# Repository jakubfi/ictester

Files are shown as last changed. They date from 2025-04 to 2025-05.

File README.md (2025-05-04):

# Logic IC Tester
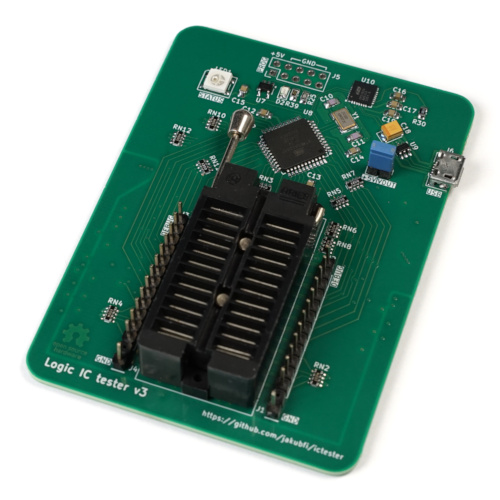
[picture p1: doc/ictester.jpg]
IC Tester

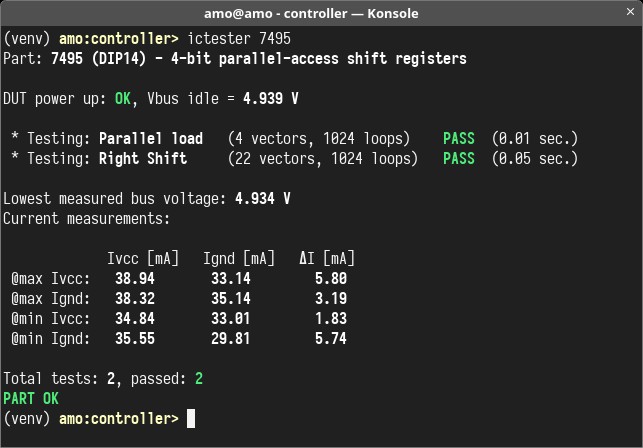
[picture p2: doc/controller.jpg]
Software


Main goal of this project was to make a logic IC tester that allows adding new tests and support for new ICs easily.

## Features

* fully programmable (client-side, in python)
* designed for 5 V TTL logic, but other 5 V logic families can be tested too
* current limiting to 200mA
* current and voltage measurement on VCC and GND pins
* 1.7 μs (<=16-pin ICs) and 2.15 μs (>16-pin ICs) per single logic test cycle
* built-in tests for 4164 and 41256 memories (MARCH C- test in read+write, read/write and page access modes)
* built-in tests for 74121, 74122 and 74123 univibrators
* small and USB powered

## Components

Project is split into three parts:

* [controller](controller) - software for controlling the tester. Look there for command line usage.
* [firmware](fw) - IC tester firmware
* [hardware](hw) - KiCad project files (see also [this pdf](doc/ictester.pdf) for schematic)

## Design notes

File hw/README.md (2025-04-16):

KiCad project files for Logic IC Tester.

See also [pdf schematic](../doc/ictester.pdf)

# Connectors and jumpers

* J1, J2, J3, J4 - debug connectors. Duplicate ZIF socket connections (plus additional GND connections) and allow
  connecting external measurement equipment. Can also be used for testing ICs and circuits outside the ZIF socket.
* J5 - MCU programmer interface.
* J6 - USB port
* J7 - jumper shorting +5V to DUT power supply lines. Normally closed. Can be used for measuring IC current
  or for supplying the IC with external power.

# CP2102N setup

To complete the hardware setup, CP2102N USB UART transceiver needs to be programmed with the following values:

* iManufacturer = mera400.pl
* iProduct = ictester
* MaxPower = 200mA

One possible way of programming it is to use [this](https://github.com/VCTLabs/cp210x-program/tree/master/ext/badge) tool:

`cp2102 -p "ictester" -m "mera400.pl" -x 200`

You can also use one of the tools provided by the manufacturer - Silicon Labs.

This step is not required, although without it no device autodetection will be possible.

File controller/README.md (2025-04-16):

# Logic IC Tester Control Software

This software communincates with the logic IC tester using [binary protocol](../doc/protocol.md) over a serial connection.
It first sets up all the DUT connections according to IC pin description and then runs tests for the selected IC.

# Installation

For both Linux and Windows installation requirements are the same:

* `python` >=3.6
* `git`

Note for Windows users: both git and python need to be available in your PATH for the installation to work.

Optionally create a new virtual environment:
```
virtualenv ictester
. ictester/bin/activate
```

Install the package:
```
pip install -e "git+https://github.com/jakubfi/ictester/#egg=ictester&subdirectory=controller"
```
Alternatively, clone the repo manually and install:
```
git clone https://github.com/jakubfi/ictester
cd ictester/controller
pip install .
```

# Usage

To list supported ICs use: `ictester --list`. `--list-all` will also list all tests for each part.
To run tests for a selected part use: `ictester <part>`.
To display help, use `ictester --help`

Note for Windows users: you'll need Silicon Labs CP210x USB to UART Bridge Driver installed
for the communication with IC tester to work. Also, device autodetection may fail.
In such case, use `--device COMx` option.

Other options when running a test:

* `-d DEVICE` or `--device DEVICE` - Serial port where the IC tester is connected. Required only when autodetection fails for some reason.
* `-l LOOPS` or `--loops LOOPS` - Test loop count (1..65535)
* `-t TEST` or `--test TEST` - Selects specific test to run
* `-D DELAY` or `--delay DELAY` - additional DUT output read delay in μs (for logic tests only, 13107 μs max, rounded to nearest 0.2 μs)
* `-v` or `--verbose` - Verbose output. Repeat for even more verbosity.
* `--safety-off` - Test the DUT even if overcurrent condition is detected.

Apart from the program output, tester hardware signals its state with a status LED:

* white - tester powered up and ready
* amber - DUT connected, test session running (do not remove the DUT from the socket)
* green - last test session finished with success (part is OK)
* red - last test session finished with failure (part is defective)
* purple - error encountered during session run

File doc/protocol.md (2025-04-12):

__WARNING: protocol is not yet finalized nor fully implemented__

# Overview

Dialog between the software and the tester are conducted using messages. There are two types of messages:

 * commands,
 * responses.

Dialog is always initiated with a command sent by the software controlling the tester. Tester always responds with a response.

All BYTES are unsigned. All WORDS are unsigned 16-bit values, little-endian.

## Available commands

| Command | Value | Description |
|---|---|---|
| `CMD_HELLO` | 1 | Check comms and get tester information |
| `CMD_DUT_SETUP` | 2 | Configure tester for the DUT |
| `CMD_DUT_POWERUP` | 3 | Power up the DUT |
| `CMD_TEST_SETUP` | 4 | Setup the test |
| `CMD_VECTORS_LOAD` | 5 | Load test vectors (optional, if used by the test) |
| `CMD_TEST_RUN` | 6 | Run the test |
| `CMD_DUT_DISCONNECT` | 7 | Power down the DUT, disconnect from the tester |

## Available responses

| Response | Value | Meaning |
|---|---|---|
| `RESP_HELLO` | 128 | Tester information |
| `RESP_OK` | 129 | Command executed |
| `RESP_PASS` | 130 | Test finished successfully |
| `RESP_FAIL` | 131 | Test finished with failure |
| `RESP_ERR` | 132 | Error |
| `RESP_TIMING_ERROR`  | 133 | Test finished with read timing error |

# Command description

## Hello

To verify that controlling software can work with the hardware, initial "Hello" handshake has to be performed.

### Command format

* 1 BYTE: command `CMD_HELLO`

### Valid responses

Tester always responds with `RESP_HELLO`, described in later section.

## DUT Setup

Before any other command, tester needs to be set up for the specific DUT.
This command informs the tester how to address DUT pins and sets ZIF socket pin functions for the DUT.
Protocol allows sending 1 or 2 pin configurations when setting up the DUT. One configuration is used
in most cases. Two configurations are required for DUTs with bidirectional pins, where pin roles
change from test to test.

### Command format

* 1 BYTE: command: `CMD_DUT_SETUP`
* 1 BYTE: `t` = package type (1=DIP)
* 1 BYTE: `p` = number of all DUT pins ([14, 16, 20, 24])
* 1 BYTE: `c` = number of pin configurations (min 1, max 4)
* `c` PIN CONFIGURATIONS (internally numbered starting from `0`):
  * `p` BYTES: `p` ZIF pin functions for each DUT pin. 1 byte each, starting from pin 1. See table below.

| ZIF Function | Value | MCU Pin Function | SW Function | Default DUT use |
|---|---|---|---|---|
| `ZIF_OUT` | 1 | output | - | TTL input |
| `ZIF_IN_HIZ` | 2 | input HiZ | - | TTL output, not connected  |
| `ZIF_IN_PU_STRONG`  | 3 | input HiZ | pull-up 4.7 kΩ | open-collector output |
| `ZIF_IN_PU_WEAK` | 4 | input with weak pullup | - | TTL output, 3-state output |
| `ZIF_OUT_SINK` | 5 | output driven low (sink)  | - | open-emitter |
| `ZIF_C` | 6 | input HiZ | capacitor 470 pF | univibrator C connection |
| `ZIF_OUT_SOURCE` | 7 | output driven high (sink) | - | - |
| `ZIF_VCC` | 128 | input HiZ | VDUT (+5 V) | VCC (+5 V) |
| `ZIF_GND` | 129 | input HiZ | GND | GND |

### Valid responses

* `RESP_OK` - DUT configuration accepted
* `RESP_ERR` - DUT configuration not accepted

## DUT Power Up

This command causes the tester to apply power to the DUT. Requires the DUT to be set up first.

DUT connection is done in 3 steps:

* connect GND and VCC pins,
* apply power to the VCC pin
* measure GND and VCC current and bus voltage

If measured current exceeds 190mA, overcurrent is reported and DUT is disconnected.

### Command format

* 1 BYTE: command: `CMD_DUT_POWERUP`
* 1 BYTE: safety\_off: 1=disable overcurrent check, 0=check for overcurrent

### Valid responses

* `RESP_OK` - DUT connected
* `RESP_ERR` - DUT cannot be connected

## DUT Disconnect

This command causes the tester to power down the DUT and deconfigure it's pin connections.
Note that DUT is also immediately disconnected by the tester if a test fails.

DUT disconnection is done in 3 steps:

* disconnect power to the DUT
* disconnect VCC, GND, pull-ups and C pins,
* drain charges from DUT pins and bypass caps
* deconfigure MCU pins (set all pins as HiZ)

### Command format

* 1 BYTE: command: `CMD_DUT_DISCONNECT`

### Valid responses

* `RESP_OK` - DUT disconnected

## Test Setup

Sets up the test. Requires the DUT to be set up first.

### Command format

* 1 BYTE: command: `CMD_TEST_SETUP`
* 1 BYTE: DUT pin configuration number used by the test
  (configuration `0` is available for every DUT, more may be available in some cases. See `CMD_DUT_SETUP`)
* 1 BYTE: test type. Algorithm used to test the DUT. See table below for test types available.
* TEST PARAMETERS: depend on the test type, see below.

| Test type | Value | Description |
|---|---|---|
| `TEST_LOGIC` | 1 | Logic ICs. Designed for 74 family, but suitable for other families too  |
| `TEST_DRAM` | 2 | 4164 and 41256 DRAM memories |
| `TEST_UNIVIB` | 3 | 74121, 74122 and 74123 monostable monovibrators |

### Valid responses

* `RESP_OK` - test setup successfull
* `RESP_ERR` - test setup failed

### Test types

Available test types and their specific requirements are described below.

#### Logic IC test

`TEST_LOGIC` (1) is designed to test 74 logic (both combinatorial and sequential), but suitable for many other IC families.
It's a basic, generic test that uses test vectors (uploaded with a separate command) to verify IC functionality by
setting its inputs to given values and checking if IC outputs match test vector outputs.

Test parameters:

* 1 WORD: additional delay (in 200 ns units) before checking DUT outputs. 0 for no delay.
* `n` BYTES: I/O pin usage in test vectors (n=2 for 14-pin and 16-pin devices, n=3 for >16-pin devices):
  * each bit: 1=I/O pin used by the test, 0=pin not used by the test
  * 1st byte contains lowest pin numbers, bit 0 in each byte describes pin with the lowest number

#### 4164 and 41256 DRAM memory test

`TEST_DRAM` (2) is designed to test 4164 and 41256 DRAM memory chips. There are three tests available, all using MARCH C- algorithm:

* read-modify-write - test is done using read-modify-write memory access,
* read+write - test is done using separate "read" and "write" operations,
* page mode - test is done using page reads and writes, treating the whole page as a single word.

Test parameters:

* 1 BYTE: tested device:
  * 1 = 4164 (64kbit),
  * 2 = 41256 (256kbit).
* 1 BYTE: test type:
  * 1 = read-modify-write,
  * 2 = read+write,
  * 3 = page mode.

#### 7412x univibrator test

`TEST_UNIVIB` (3) is designed to test 74121, 74122 and 74123 univibrators. Test does not use vectors and uses the following parameters:

* 1 BYTE: tested device:
  * 0 = 74121,
  * 1 = 74122,
  * 2 = 74123 univibrator 1,
  * 3 = 74123 univibrator 2
* 1 BYTE: test type:
  * 0 = conditions which should not trigger the device
  * 1 = conditions that should trigger the device
  * 2 = retrigger (not available for 74121)
  * 3 = clear (not available for 74121)
  * 4 = cross-trigger check (only for 74123)
  * 5 = trigger with rising clear edge (not available for 74121)

## Vectors upload

Upload test vectors. Requires the test to be set up first. Test needs to use vectors.

### Command format

* 1 BYTE: command: `CMD_VECTORS_LOAD`
* 1 WORD: `v` = number of test vectors, >0.
* `v` VECTORS

Each vector consists of 2 (for <=16-pin devices) or 3 (for >16-pin devices) BYTES.
Each byte contains bit values for 8 consecutive DUT pins.
For each input, bit value is set on DUT input. For each output, bit value is compared to DUT output. Bits map to pins as follow:

```
        .----.----.----.----.----.----.----.----.
BYTE 1: |  8 |  7 |  6 |  5 |  4 |  3 |  2 |  1 |
        +----.----.----.----.----.----.----.----+
BYTE 2: | 16 | 15 | 14 | 13 | 12 | 11 | 10 |  9 |
        +----.----.----.----.----.----.----.----+
BYTE 3: | 24 | 23 | 22 | 21 | 20 | 19 | 18 | 17 | (only for >16-pin devices)
        `----`----`----`----`----`----`----`----`
```

* Pins absent in the tested device are ignored (eg. for 14-pin devices two most significant bits of BYTE 2 are ignored).
* Non-I/O pins and pins not declared as inputs or outpus in the test are ignored, with one **exception** described below.

**Bit for VCC pin has a special meaning.**
Since it's never set nor read, tester uses it to decide whether DUT outputs should be checked at all.
If VCC pin is set to "1" for a given vector, test result for this vector is not checked.
Such vectors are used for DUT state setup and in sequential logic tests, where output has to be checked
only after the clock/strobe input changes.

### Valid responses

* `RESP_OK` - vectors uploaded successfully
* `RESP_ERR` - vector upload failed

## Run Test

Run the uploaded test. Requires test to be set and vectors to be uploaded (if required by the test).
If the test fails, DUT is immediately disconnected.

### Command format

* 1 BYTE: command: `CMD_TEST_RUN`
* 1 WORD: number of loops, 0 for infinite testing.

### Valid responses

* `RESP_ERR` - not possible to execute the test
* `RESP_PASS` - test executed, passed
* `RESP_FAIL` - test executed, failed

# Responses

## Hello

* 1 BYTE: `RESP_HELLO`
* 1 BYTE: protocol version
* 1 BYTE: firmware version
* 6 BYTES: reserved, unused but always sent and received

If protocol version reported by the hardware differs from protocol version supported
by the software, software refuses operation.
If firmware version is lower than supported by the software, operation can continue,
but not all tests available in the software can be run..
If firmware version is higher than supported by the software, operation can continue,
but not all features available in the hardware may be available to the software.

## Command OK

This response is sent when command has been successfully executed.

* 1 BYTE: response: `RESP_OK`

## Command error

This response is sent when a command cannot be executed or the execution failed.

* 1 BYTE: response: `RESP_ERR`
* 1 BYTE: error code from the table below

| Command | Value | Description |
|---|---|---|
| `ERR_UNKNOWN` | 0 | Error code was not set (likely a software bug) |
| `ERR_CMD_UNKNOWN` | 1 | Unknown command |
| `ERR_CMD_TOOBIG` | 2 | Command didn't fit in the receive buffer |
| `ERR_CRC` | 3 | CRC transmission error detected |
| | 4 | (unused) |
| `ERR_PACKAGE` | 5 | Unsupported package type |
| `ERR_PIN_CNT` | 6 | Unsupported pin count |
| `ERR_PIN_FUNC` | 7 | Unknown pin function |
| `ERR_PIN_COMB` | 8 | Bad pin function combination (eg. VCC+GND) |
| | 9 | (unused) |
| `ERR_TEST_TYPE` | 10 | Unsupported test type |
| | 11 | (unused) |
| `ERR_VECT_NUM` | 12 | Wrong number of test vectors (<1 or too many) |
| `ERR_PINCFG_CNT` | 13 | Wrong pin configuration count |
| `ERR_PINCFG_NUM` | 14 | Wrong pin configuration number (config not set) |
| | 15 | (unused) |
| `ERR_PIN_FUNC_UNAVAILABLE` | 16 | Function not available for a pin |
| `ERR_NO_PINCFG` | 17 | No pin configuration active |
| `ERR_UNKNOWN_CHIP` | 18 | Selected chip type is unknown |
| `ERR_UNKNOWN_TEST` | 19 | No such test for selected chip |
| `ERR_OVERCURRENT` | 20 | Overcurrent detected while connecting DUT |

## Test PASS

This response is sent only for `CMD_TEST_RUN` command, when the test passes successfully.

* 1 BYTE: response: `RESP_PASS`

## Test FAIL

This response is sent only for `CMD_TEST_RUN` command, when the test fails.
Note that when test fails, DUT is immediately disconnected by the tester.

* 1 BYTE: response: `RESP_FAIL`
* FAILURE DESCRIPTION. Depends on the test type, see below.

### `TEST_LOGIC` failure

  * 1 WORD: vector number that test failed on
  * `n` bytes of pin data - failing vector. 2 or 3 bytes, format as for the pin mask in the test configuration.

### `TEST_DRAM` failure

  * 1 WORD: failing row address
  * 1 WORD: failing column address
  * 1 BYTE: failing MARCH C- step

### `TEST_UNIVIB` failure

Test sends no additional description.

## Test timing error

This response is sent only for `CMD_TEST_RUN` command and indicates output read timing error.
5 μs after the initial test vector failure, vector is tested again. If that second check
passes, `RESP_TIMING_ERROR` is sent in response. Otherwise test fails with `RESP_FAIL`.

* 1 BYTE: response: `RESP_TIMING_ERROR`

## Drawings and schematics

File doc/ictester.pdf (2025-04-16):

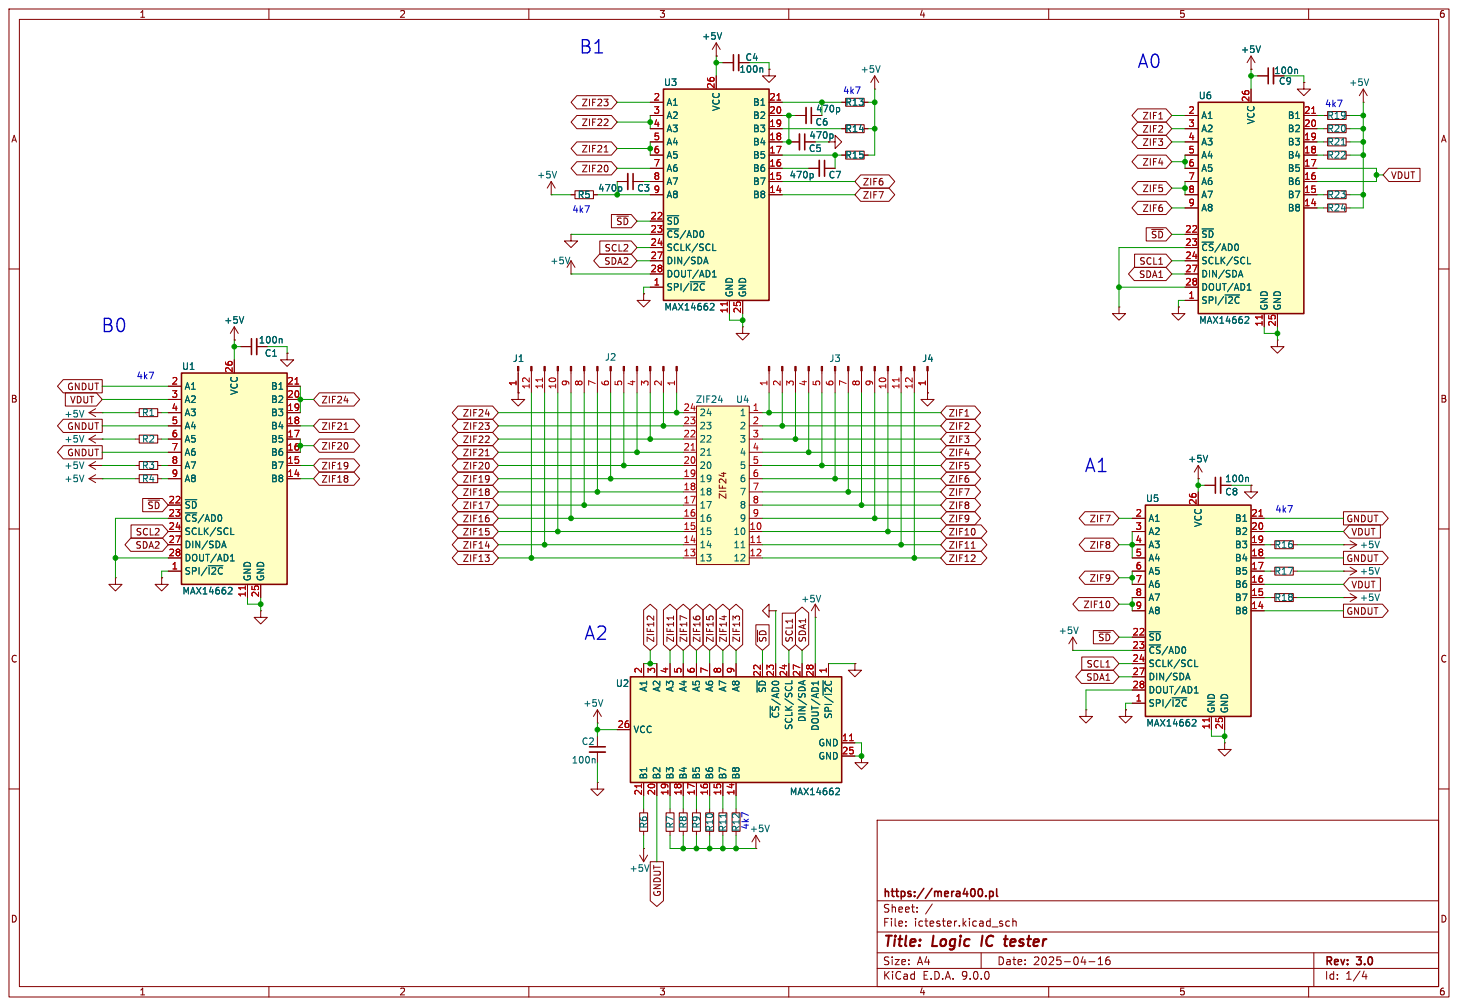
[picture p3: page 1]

Id: 1/4 Title: Logic IC tester File: ictester.kicad_sch Sheet: / https://mera400.pl

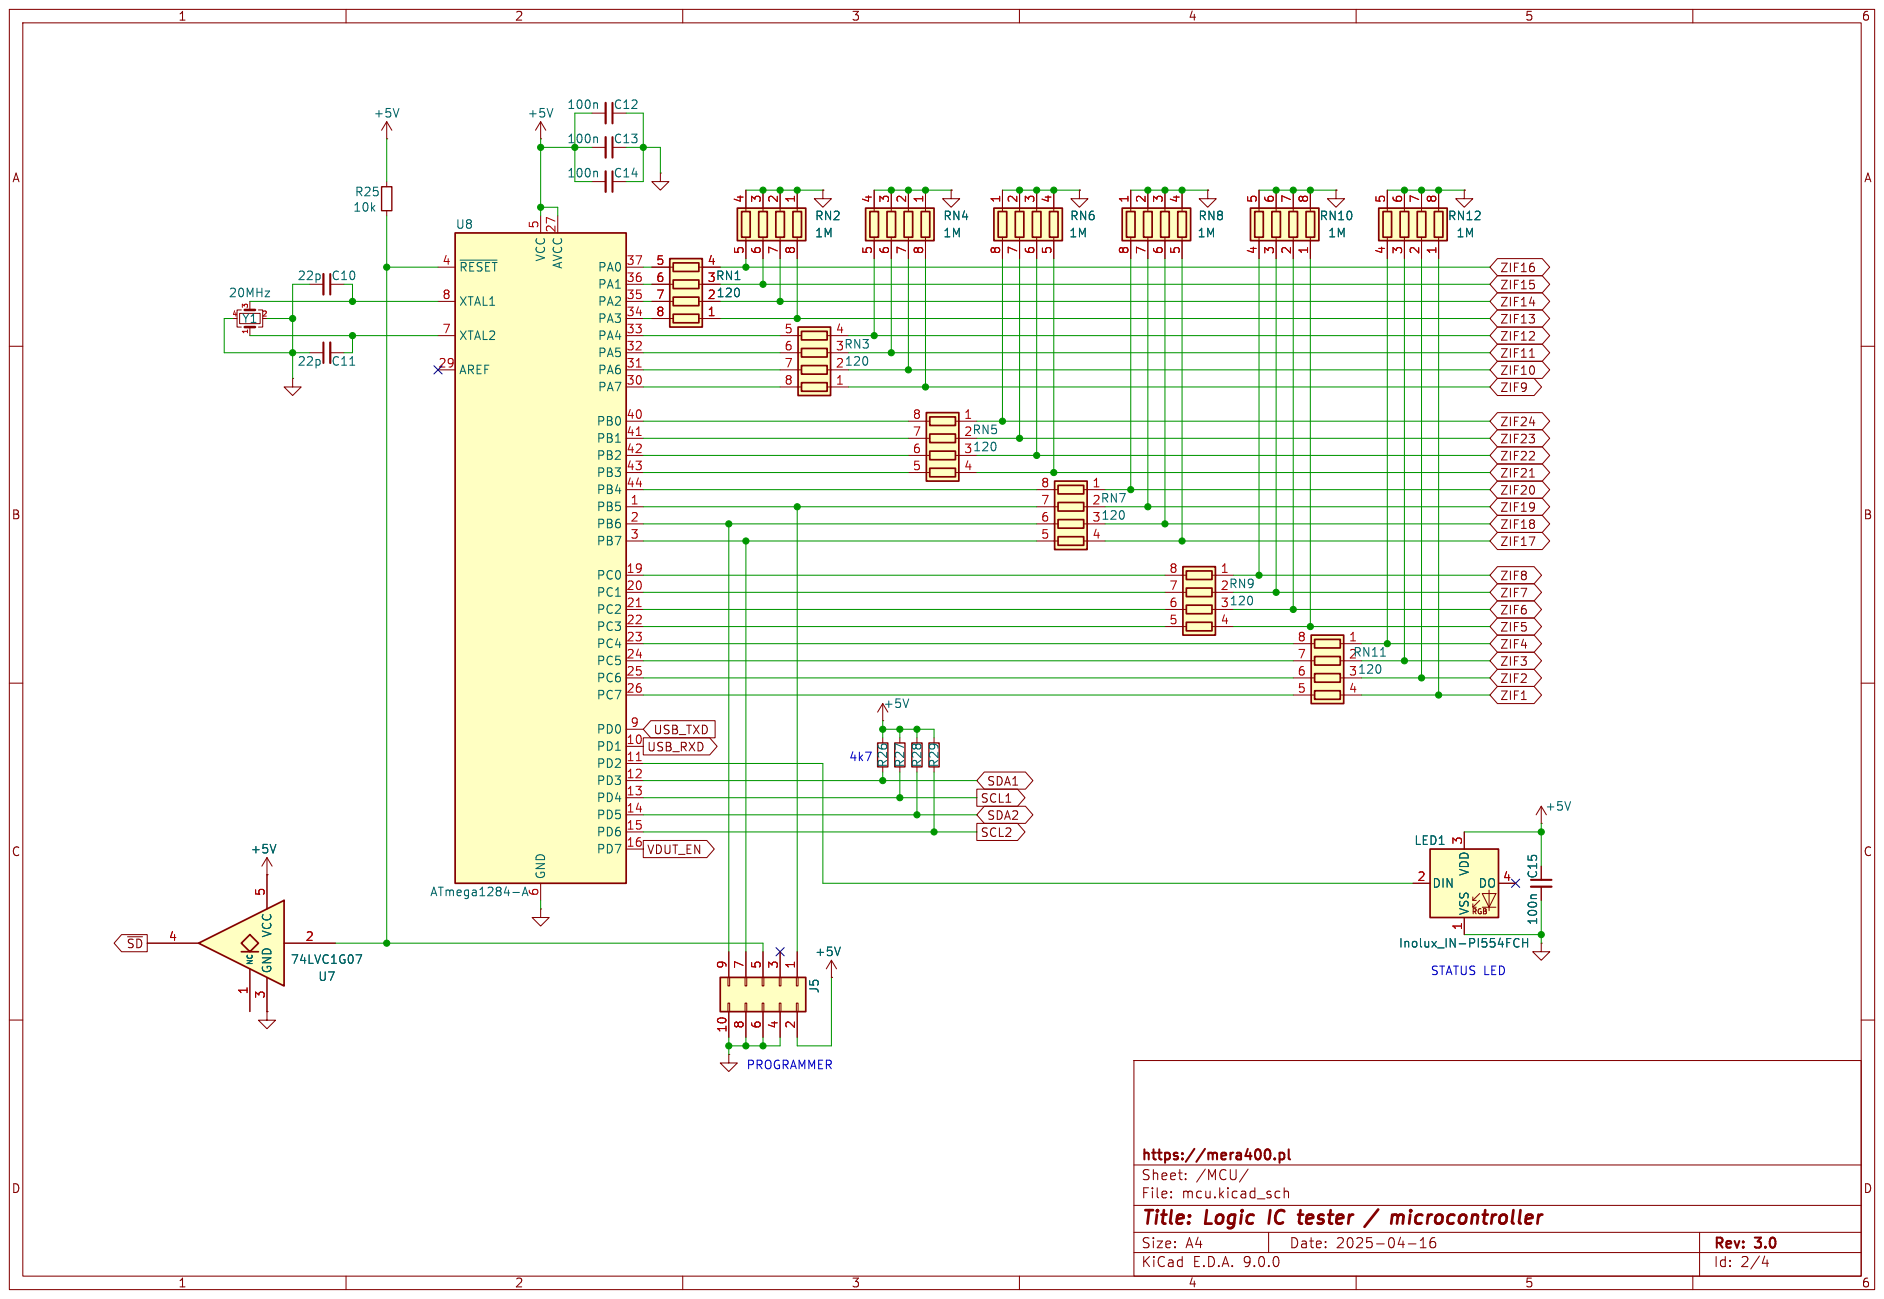
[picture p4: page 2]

Id: 2/4 Title: Logic IC tester / microcontroller File: mcu.kicad_sch Sheet: /MCU/ https://mera400.pl

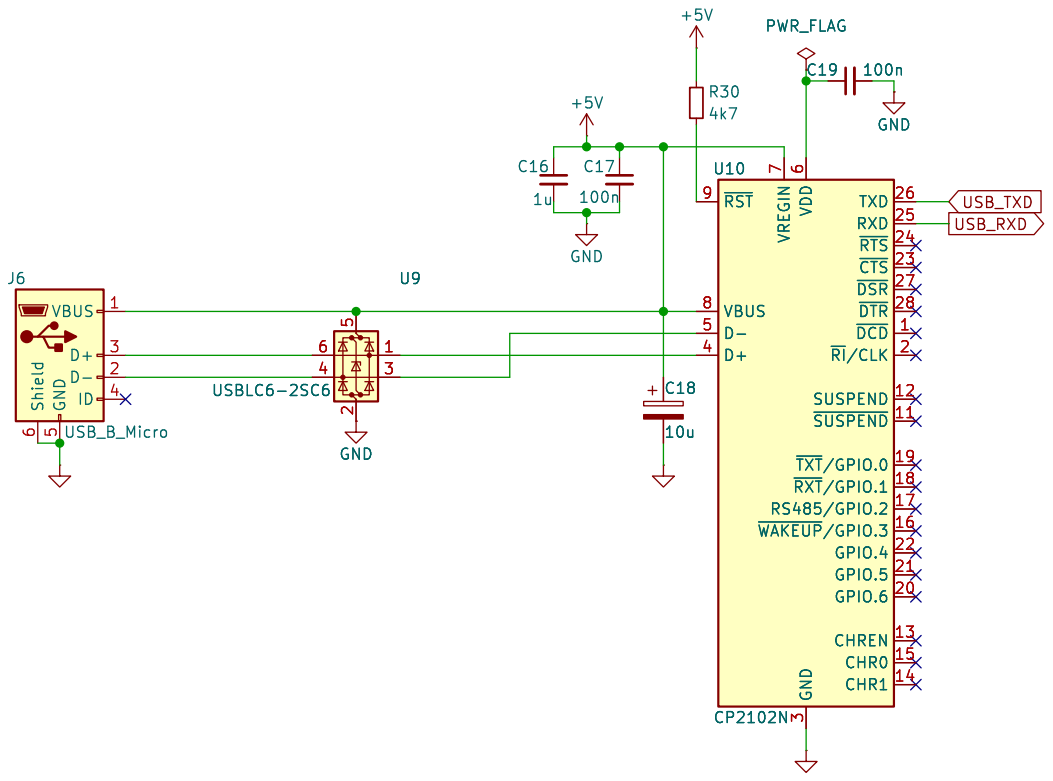
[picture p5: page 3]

3 TXD 26 RXD 25 ~{RTS} 24 ~{CTS} 23 ~{DSR} 27 ~{DTR} 28 ~{DCD}1 ~{RI}/CLK2 SUSPEND 12 ~{SUSPEND}11 ~{TXT}/GPIO.019 ~{RXT}/GPIO.118 RS485/GPIO.2 17 ~{WAKEUP}/GPIO.316 GPIO.4 22 GPIO.5 21 GPIO.6 20 CHREN 13 CHR0 15 CHR1 14 GND

3 TXD 26 RXD 25 ~{RTS} 24 ~{CTS} 23 ~{DSR} 27 ~{DTR} 28 ~{DCD}1 ~{RI}/CLK2 SUSPEND 12 ~{SUSPEND}11 ~{TXT}/GPIO.019 ~{RXT}/GPIO.118 RS485/GPIO.2 17 ~{WAKEUP}/GPIO.316 GPIO.4 22 GPIO.5 21 GPIO.6 20 CHREN 13 CHR0 15 CHR1 14 U10 CP2102N

File: usb.kicad_sch Sheet: /USB/ https://mera400.pl

Id: 3/4 Title: Logic IC tester / USB bus

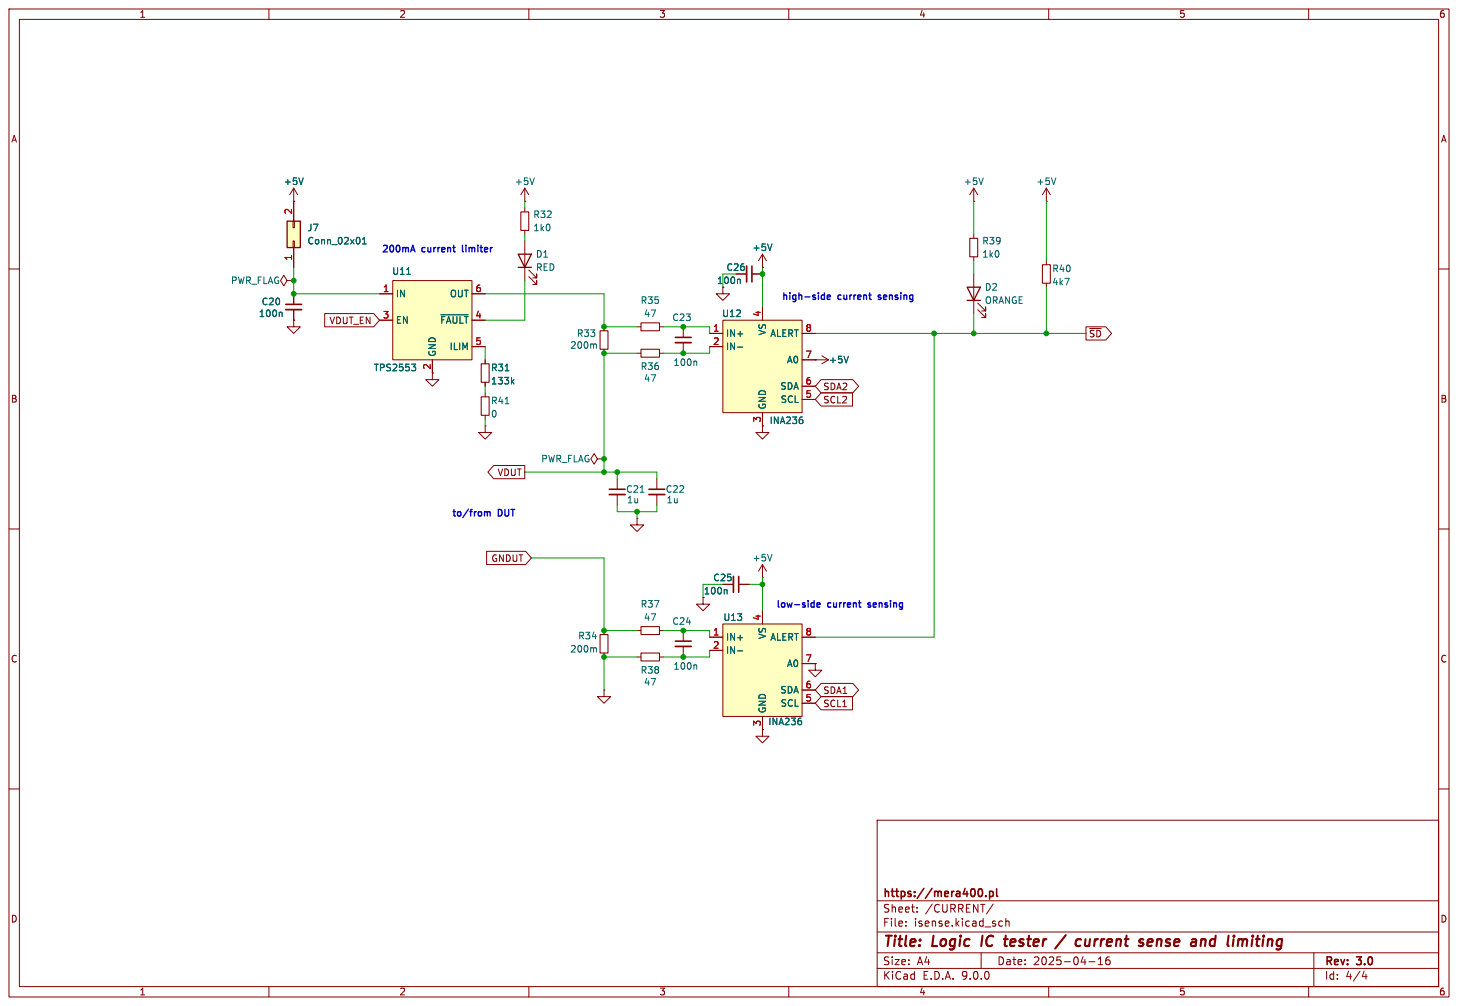
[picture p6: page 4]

File: isense.kicad_sch Sheet: /CURRENT/ https://mera400.pl C21

Id: 4/4 Title: Logic IC tester / current sense and limiting

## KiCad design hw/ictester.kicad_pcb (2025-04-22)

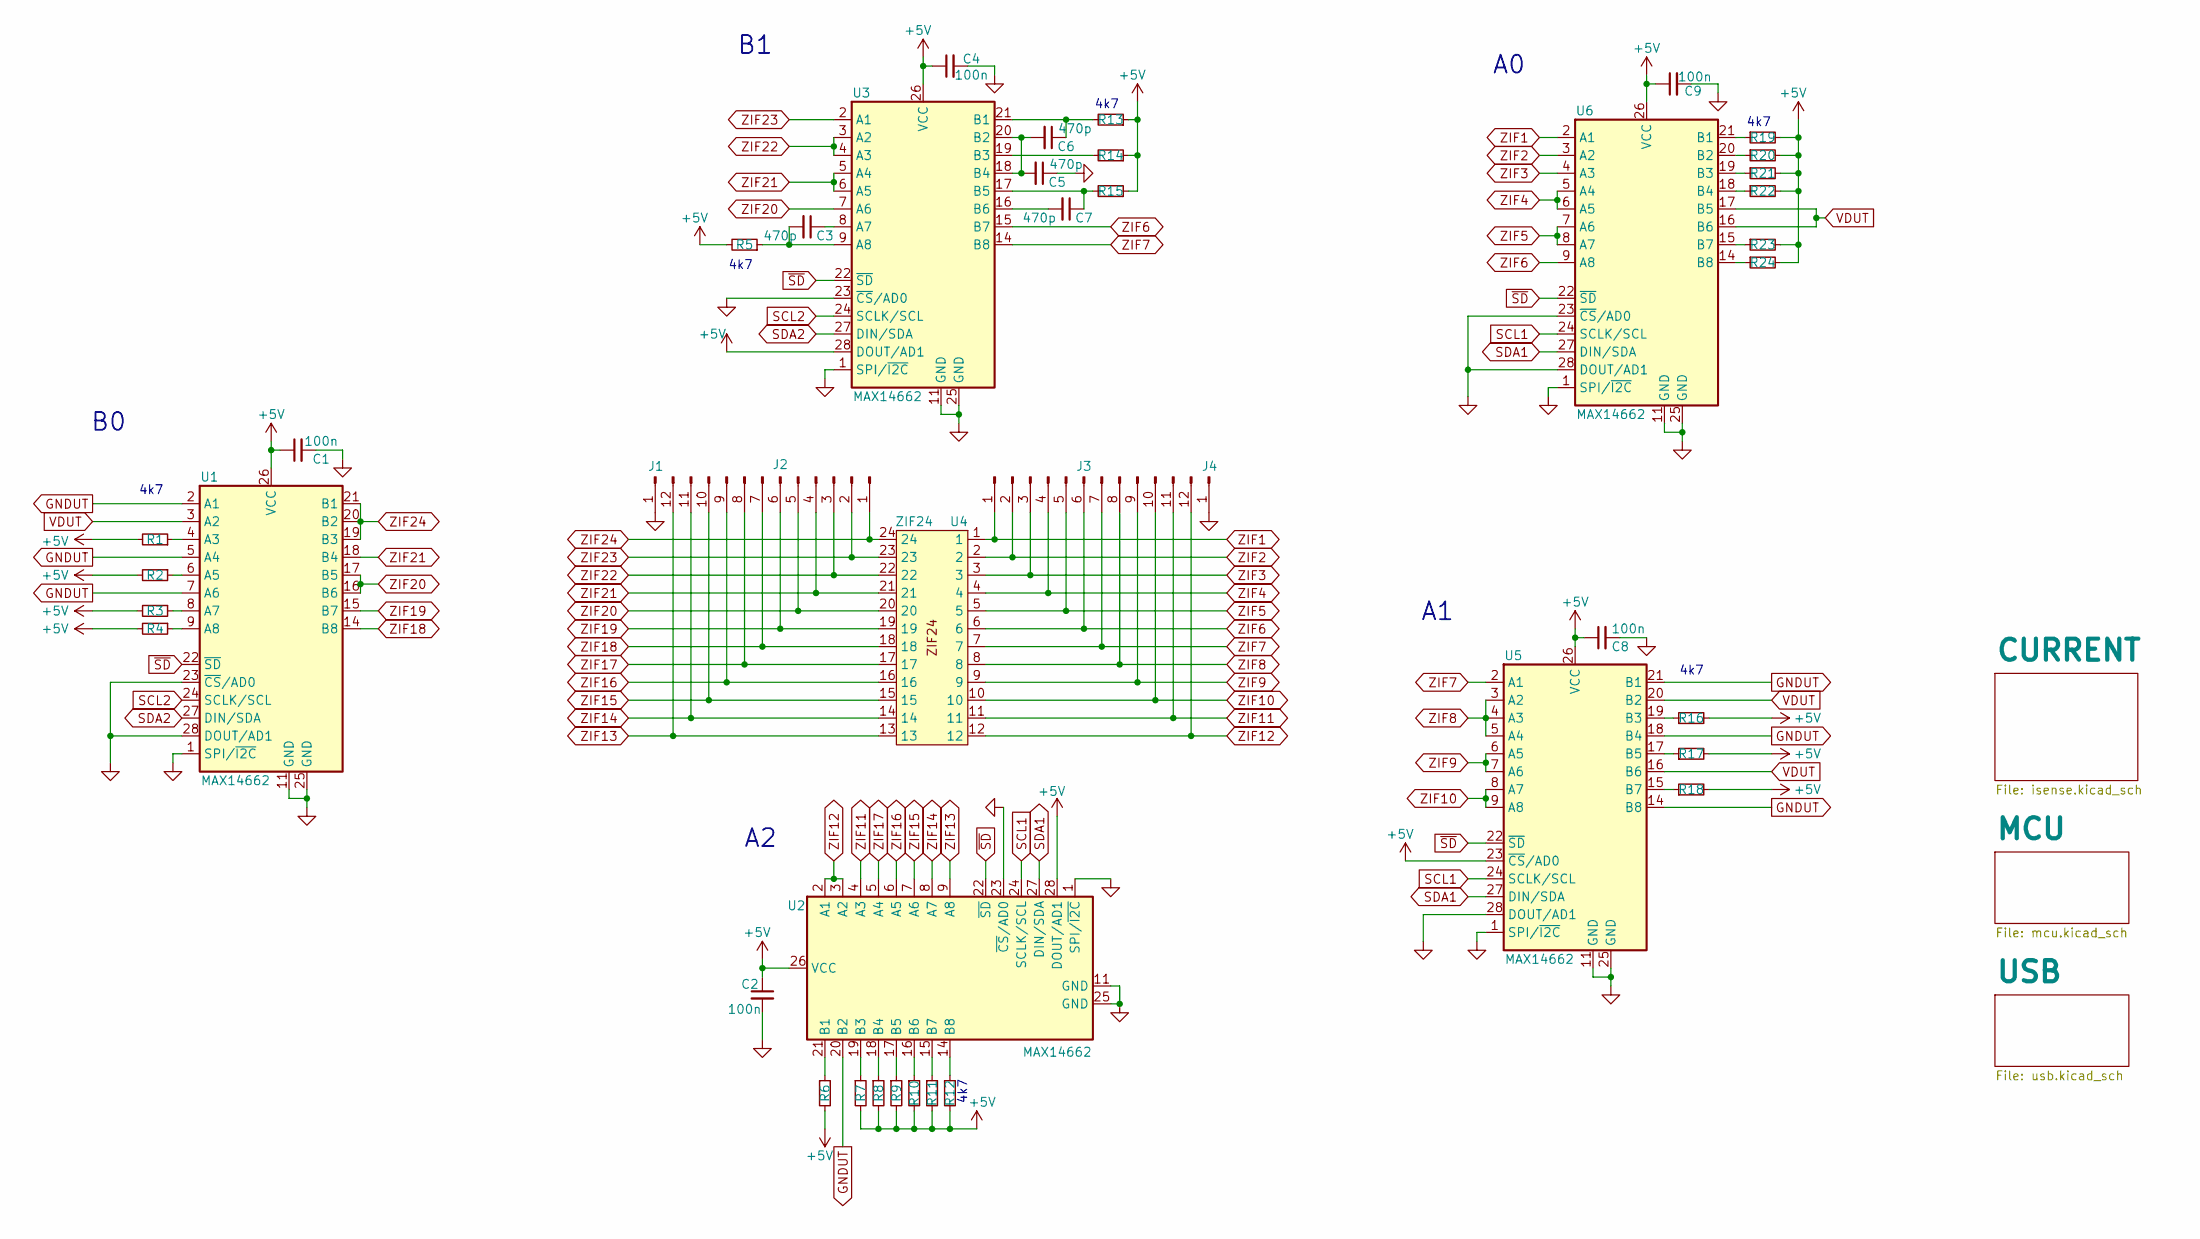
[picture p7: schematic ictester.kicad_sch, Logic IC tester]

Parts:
C1, C2, C4, C8, C9: 100n; C_0805_2012Metric_Pad1.18x1.45mm_HandSolder
C3, C5, C6, C7: 470p; C_0805_2012Metric_Pad1.18x1.45mm_HandSolder
J1, J4: Conn_01x01_Pin; PinHeader_1x01_P2.54mm_Vertical
J2, J3: Conn_01x12_Pin; PinHeader_1x12_P2.54mm_Vertical
R1, R2, R3, R4, R5, R6, R7, R8, R9, R10, R11, R12, R13, R14, R15, R16, R17, R18, R19, R20, R21, R22, R23, R24: 4k7; R_0805_2012Metric_Pad1.20x1.40mm_HandSolder
U1, U2, U3, U5, U6: MAX14662; QFN-28-1EP_4x4mm_P0.4mm_EP2.6x2.6mm
U4: ZIF24; DIP_Socket-24_W11.9_W12.7_W15.24_W17.78_W18.5_3M_224-1275-0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

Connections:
+5V: C1.1, C2.1, C4.1, C8.1, C9.1, R1.2, R2.2, R3.2, R4.2, R5.2, R6.2, R7.2, R8.2, R9.2, R10.2, R11.2, R12.2, R13.1, R14.1, R15.1, R16.2, R17.2, R18.2, R19.2, R20.2, R21.2, R22.2, R23.2, R24.2, U1.26 (VCC), U2.26 (VCC), U2.28 (DOUT/AD1), U3.26 (VCC), U3.28 (DOUT/AD1), U5.23 (~CS/AD0), U5.26 (VCC), U6.26 (VCC); also elsewhere on the board
GND: C1.2, C2.2, C4.2, C5.1, C8.2, C9.2, J1.1, J4.1, U1.1 (SPI/~I2C), U1.11 (GND), U1.23 (~CS/AD0), U1.25 (GND), U1.28 (DOUT/AD1), U1.29 (GND), U2.1 (SPI/~I2C), U2.11 (GND), U2.23 (~CS/AD0), U2.25 (GND), U2.29 (GND), U3.1 (SPI/~I2C), U3.11 (GND), U3.23 (~CS/AD0), U3.25 (GND), U3.29 (GND), U5.1 (SPI/~I2C), U5.11 (GND), U5.25 (GND), U5.28 (DOUT/AD1), U5.29 (GND), U6.1 (SPI/~I2C), U6.11 (GND), U6.23 (~CS/AD0), U6.25 (GND), U6.28 (DOUT/AD1), U6.29 (GND); also elsewhere on the board
GNDUT: U1.2 (A1), U1.5 (A4), U1.7 (A6), U2.20 (B2), U5.14 (B8), U5.18 (B4), U5.21 (B1); also elsewhere on the board
unnamed: R1.1, U1.4 (A3)
unnamed: R2.1, U1.6 (A5)
unnamed: R3.1, U1.8 (A7)
unnamed: R4.1, U1.9 (A8)
unnamed: R6.1, U2.21 (B1)
unnamed: R7.1, U2.19 (B3)
unnamed: R8.1, U2.18 (B4)
unnamed: R9.1, U2.17 (B5)
unnamed: R10.1, U2.16 (B6)
unnamed: R11.1, U2.15 (B7)
unnamed: R12.1, U2.14 (B8)
unnamed: C3.1, U3.8 (A7)
unnamed: C3.2, R5.1, U3.9 (A8)
unnamed: C6.1, R13.2, U3.21 (B1)
unnamed: C5.2, C6.2, U3.18 (B4), U3.20 (B2)
unnamed: R14.2, U3.19 (B3)
unnamed: C7.1, R15.2, U3.17 (B5)
unnamed: C7.2, U3.16 (B6)
unnamed: R16.1, U5.19 (B3)
unnamed: R17.1, U5.17 (B5)
unnamed: R18.1, U5.15 (B7)
unnamed: R19.1, U6.21 (B1)
unnamed: R20.1, U6.20 (B2)
unnamed: R21.1, U6.19 (B3)
unnamed: R22.1, U6.18 (B4)
unnamed: R23.1, U6.15 (B7)
unnamed: R24.1, U6.14 (B8)
SCL1: U2.24 (SCLK/SCL), U5.24 (SCLK/SCL), U6.24 (SCLK/SCL); also elsewhere on the board
SCL2: U1.24 (SCLK/SCL), U3.24 (SCLK/SCL); also elsewhere on the board
SDA1: U2.27 (DIN/SDA), U5.27 (DIN/SDA), U6.27 (DIN/SDA); also elsewhere on the board
SDA2: U1.27 (DIN/SDA), U3.27 (DIN/SDA); also elsewhere on the board
VDUT: U1.3 (A2), U5.16 (B6), U5.20 (B2), U6.16 (B6), U6.17 (B5); also elsewhere on the board
ZIF1: J3.1, U4.1, U6.2 (A1); also elsewhere on the board
ZIF2: J3.2, U4.2, U6.3 (A2); also elsewhere on the board
ZIF3: J3.3, U4.3, U6.4 (A3); also elsewhere on the board
ZIF4: J3.4, U4.4, U6.5 (A4), U6.6 (A5); also elsewhere on the board
ZIF5: J3.5, U4.5, U6.7 (A6), U6.8 (A7); also elsewhere on the board
ZIF6: J3.6, U3.15 (B7), U4.6, U6.9 (A8); also elsewhere on the board
ZIF7: J3.7, U3.14 (B8), U4.7, U5.2 (A1); also elsewhere on the board
ZIF8: J3.8, U4.8, U5.3 (A2), U5.4 (A3), U5.5 (A4); also elsewhere on the board
ZIF9: J3.9, U4.9, U5.6 (A5), U5.7 (A6); also elsewhere on the board
ZIF10: J3.10, U4.10, U5.8 (A7), U5.9 (A8); also elsewhere on the board
ZIF11: J3.11, U2.4 (A3), U4.11; also elsewhere on the board
ZIF12: J3.12, U2.2 (A1), U2.3 (A2), U4.12; also elsewhere on the board
ZIF13: J2.12, U2.9 (A8), U4.13; also elsewhere on the board
ZIF14: J2.11, U2.8 (A7), U4.14; also elsewhere on the board
ZIF15: J2.10, U2.7 (A6), U4.15; also elsewhere on the board
ZIF16: J2.9, U2.6 (A5), U4.16; also elsewhere on the board
ZIF17: J2.8, U2.5 (A4), U4.17; also elsewhere on the board
ZIF18: J2.7, U1.14 (B8), U4.18; also elsewhere on the board
ZIF19: J2.6, U1.15 (B7), U4.19; also elsewhere on the board
ZIF20: J2.5, U1.16 (B6), U1.17 (B5), U3.7 (A6), U4.20; also elsewhere on the board
ZIF21: J2.4, U1.18 (B4), U3.5 (A4), U3.6 (A5), U4.21; also elsewhere on the board
ZIF22: J2.3, U3.3 (A2), U3.4 (A3), U4.22; also elsewhere on the board
ZIF23: J2.2, U3.2 (A1), U4.23; also elsewhere on the board
ZIF24: J2.1, U1.19 (B3), U1.20 (B2), U1.21 (B1), U4.24; also elsewhere on the board
~SD: U1.22 (~SD), U2.22 (~SD), U3.22 (~SD), U5.22 (~SD), U6.22 (~SD); also elsewhere on the board

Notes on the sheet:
4k7

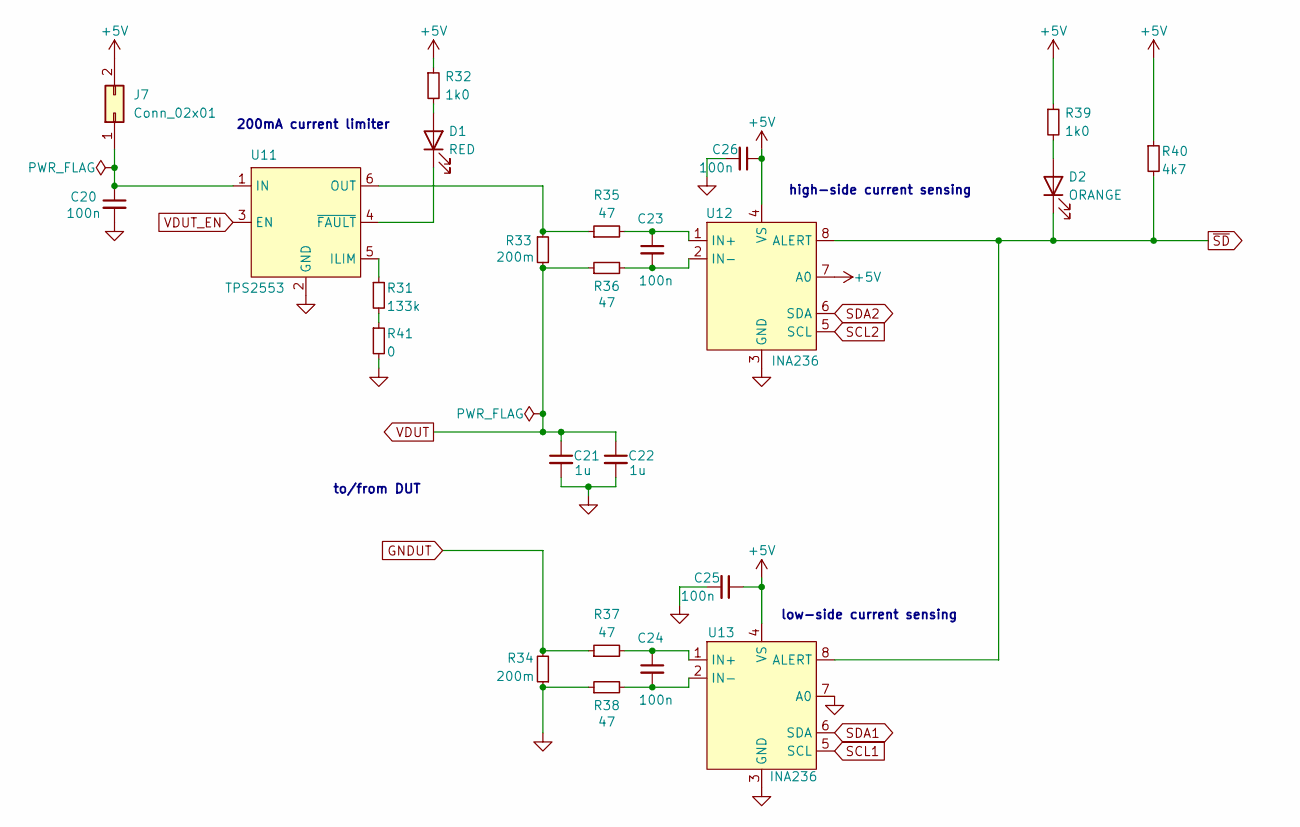
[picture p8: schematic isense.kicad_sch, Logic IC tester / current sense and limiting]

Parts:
C20, C23, C24, C25, C26: 100n; C_0805_2012Metric_Pad1.18x1.45mm_HandSolder
C21, C22: 1u; C_0805_2012Metric_Pad1.18x1.45mm_HandSolder
D1: RED; LED_0805_2012Metric_Pad1.15x1.40mm_HandSolder
D2: ORANGE; LED_0805_2012Metric_Pad1.15x1.40mm_HandSolder
J7: Conn_02x01; PinHeader_1x02_P2.54mm_Vertical
R31: 133k; R_0805_2012Metric_Pad1.20x1.40mm_HandSolder
R32, R39: 1k0; R_0805_2012Metric_Pad1.20x1.40mm_HandSolder
R33, R34: 200m; R_0805_2012Metric_Pad1.20x1.40mm_HandSolder
R35, R36, R37, R38: 47; R_0805_2012Metric_Pad1.20x1.40mm_HandSolder
R40: 4k7; R_0805_2012Metric_Pad1.20x1.40mm_HandSolder
R41: 0; R_0805_2012Metric_Pad1.20x1.40mm_HandSolder
U11: TPS2553; SOT-23-6_Handsoldering
U12, U13: INA236; SOT-23-8_Handsoldering

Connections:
+5V: C25.1, C26.1, J7.2, R32.1, R39.1, R40.1, U12.4 (VS), U12.7 (A0), U13.4 (VS); also elsewhere on the board
GND: C20.2, C21.2, C22.2, C25.2, C26.2, R34.1, R38.1, R41.2, U11.2 (GND), U12.3 (GND), U13.3 (GND), U13.7 (A0); also elsewhere on the board
GNDUT: R34.2, R37.1; also elsewhere on the board
unnamed: D1.2 (A), R32.2
unnamed: D1.1 (K), U11.4 (~FAULT)
unnamed: D2.2 (A), R39.2
unnamed: C20.1, J7.1, U11.1 (IN)
unnamed: R31.2, R41.1
unnamed: R31.1, U11.5 (ILIM)
unnamed: R33.1, R35.1, U11.6 (OUT)
unnamed: C23.1, R35.2, U12.1 (IN+)
unnamed: C23.2, R36.2, U12.2 (IN-)
unnamed: C24.1, R37.2, U13.1 (IN+)
unnamed: C24.2, R38.2, U13.2 (IN-)
SCL1: U13.5 (SCL); also elsewhere on the board
SCL2: U12.5 (SCL); also elsewhere on the board
SDA1: U13.6 (SDA); also elsewhere on the board
SDA2: U12.6 (SDA); also elsewhere on the board
VDUT: C21.1, C22.1, R33.2, R36.1; also elsewhere on the board
VDUT_EN: U11.3 (EN); also elsewhere on the board
~SD: D2.1 (K), R40.2, U12.8 (ALERT), U13.8 (ALERT); also elsewhere on the board

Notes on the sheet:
low-side current sensing
200mA current limiter
high-side current sensing
to/from DUT

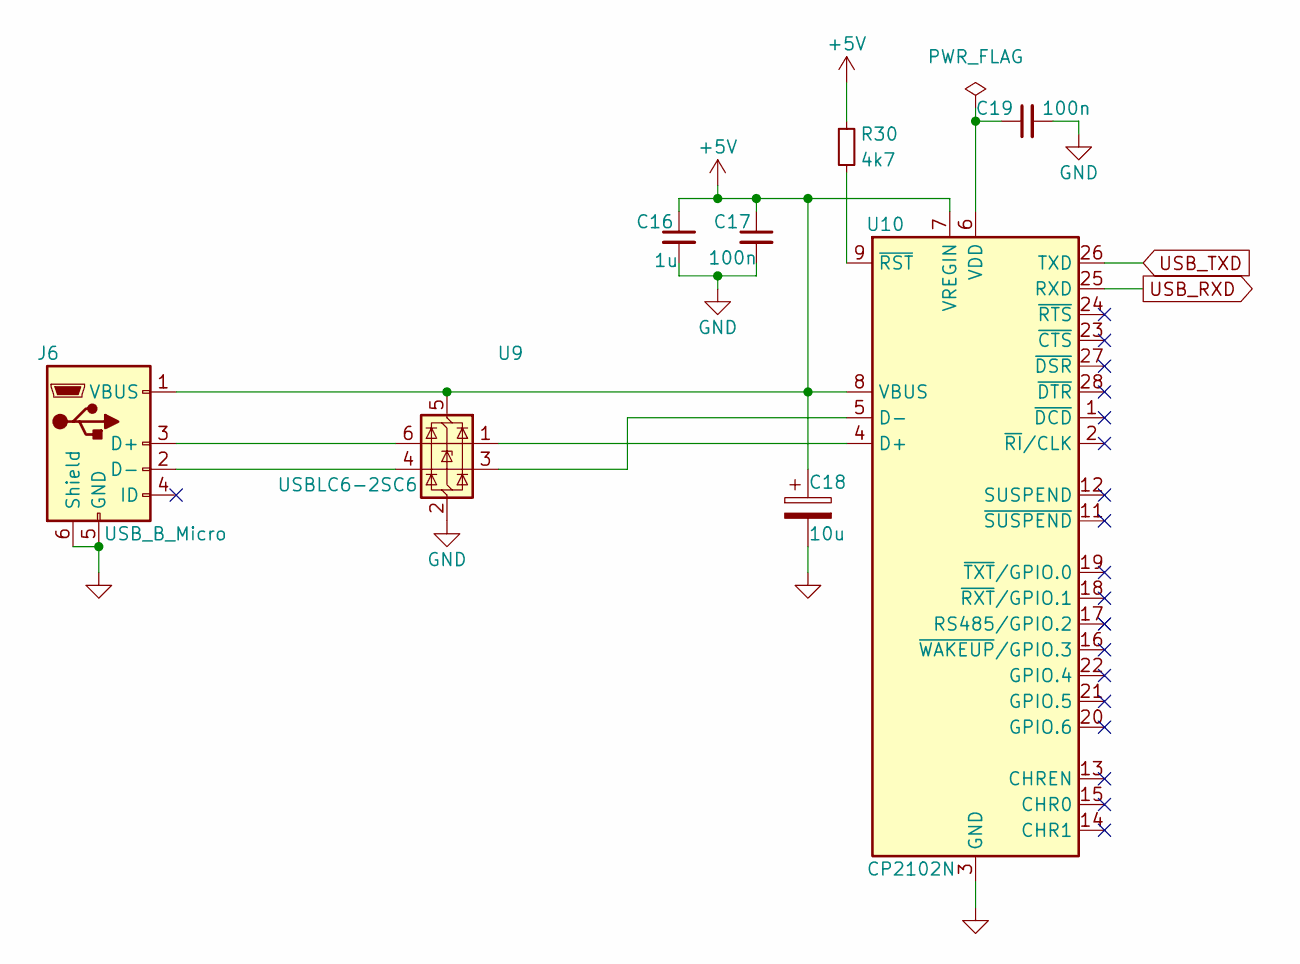
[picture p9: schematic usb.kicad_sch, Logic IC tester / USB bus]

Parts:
C16: 1u; C_0805_2012Metric_Pad1.18x1.45mm_HandSolder
C17, C19: 100n; C_0805_2012Metric_Pad1.18x1.45mm_HandSolder
C18: 10u; CP_EIA-3528-21_Kemet-B_Pad1.50x2.35mm_HandSolder
J6: USB_B_Micro; USB_Micro-B_Amphenol_10118193-0001LF_Horizontal
R30: 4k7; R_0805_2012Metric_Pad1.20x1.40mm_HandSolder
U9: USBLC6-2SC6; SOT-23-6
U10: CP2102N; QFN-28-1EP_5x5mm_P0.5mm_EP3.35x3.35mm

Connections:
+5V: C16.1, C17.1, C18.1, J6.1 (VBUS), R30.1, U9.5 (VBUS), U10.7 (VREGIN), U10.8 (VBUS); also elsewhere on the board
GND: C16.2, C17.2, C18.2, C19.2, J6.5 (GND), J6.6 (Shield), U9.2 (GND), U10.3 (GND), U10.29 (GND); also elsewhere on the board
unnamed: J6.3 (D+), U9.6 (I/O1)
unnamed: J6.2 (D-), U9.4 (I/O2)
unnamed: U9.1 (I/O1), U10.4 (D+)
unnamed: U9.3 (I/O2), U10.5 (D-)
unnamed: C19.1, U10.6 (VDD)
unnamed: R30.2, U10.9 (~RST)
USB_RXD: U10.25 (RXD); also elsewhere on the board
USB_TXD: U10.26 (TXD); also elsewhere on the board

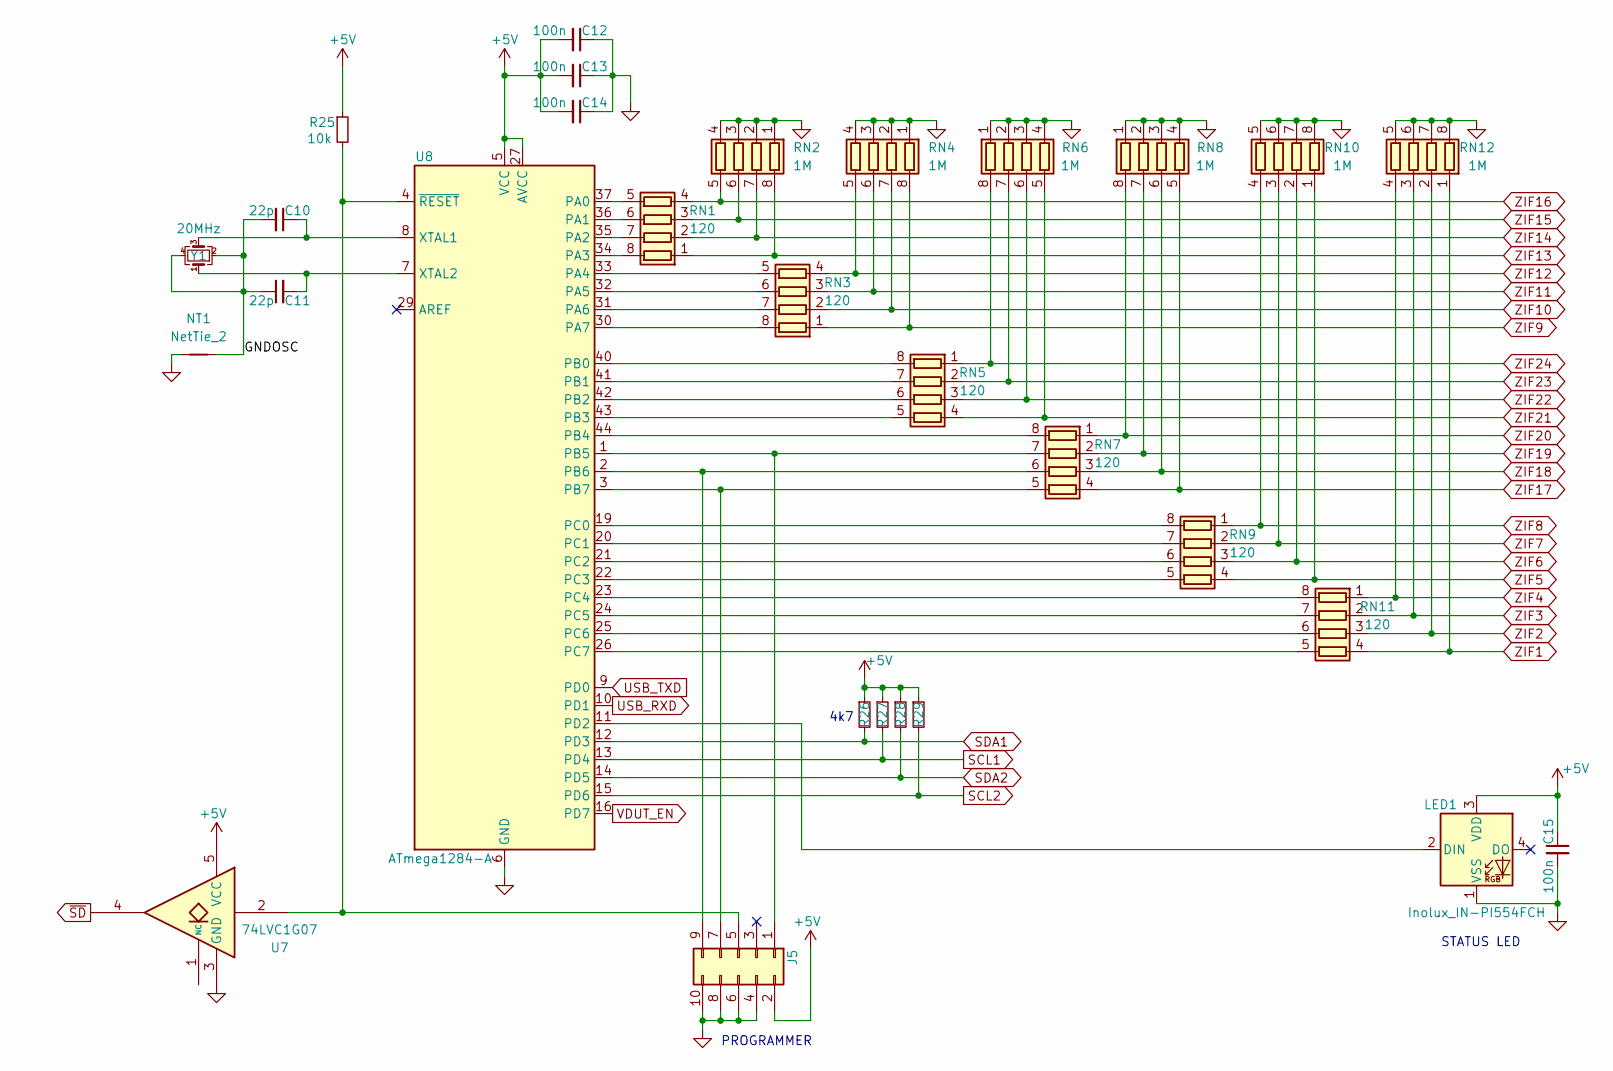
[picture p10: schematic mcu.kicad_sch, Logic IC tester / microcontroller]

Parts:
C10, C11: 22p; C_0805_2012Metric_Pad1.18x1.45mm_HandSolder
C12, C13, C14, C15: 100n; C_0805_2012Metric_Pad1.18x1.45mm_HandSolder
J5: Conn_02x05_Odd_Even; PinHeader_2x05_P2.54mm_Vertical
LED1: Inolux_IN-PI554FCH; LED_Inolux_IN-PI554FCH_PLCC4_5.0x5.0mm_P3.2mm
NT1: NetTie_2; NetTie-2_SMD_Pad0.5mm
R25: 10k; R_0805_2012Metric_Pad1.20x1.40mm_HandSolder
R26, R27, R28, R29: 4k7; R_0805_2012Metric_Pad1.20x1.40mm_HandSolder
RN1, RN3, RN5, RN7, RN9, RN11: 120; R_Array_Convex_4x0603
RN2, RN4, RN6, RN8, RN10, RN12: 1M; R_Array_Convex_4x0603
U7: 74LVC1G07; SOT-23-5_HandSoldering
U8: ATmega1284-A; TQFP-44_10x10mm_P0.8mm
Y1: 20MHz; Crystal_SMD_Abracon_ABM3C-4Pin_5.0x3.2mm

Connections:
+5V: C12.2, C13.2, C14.2, C15.1, J5.2, LED1.3 (VDD), R25.1, R26.1, R27.1, R28.1, R29.1, U7.5 (VCC), U8.5 (VCC), U8.17 (VCC), U8.27 (AVCC), U8.38 (VCC); also elsewhere on the board
/MCU/GNDOSC: C10.2, C11.1, NT1.2, Y1.2, Y1.4
GND: C12.1, C13.1, C14.1, C15.2, J5.4, J5.6, J5.8, J5.10, LED1.1 (VSS), NT1.1, RN2.1 (R1.1), RN2.2 (R2.1), RN2.3 (R3.1), RN2.4 (R4.1), RN4.1 (R1.1), RN4.2 (R2.1), RN4.3 (R3.1), RN4.4 (R4.1), RN6.1 (R1.1), RN6.2 (R2.1), RN6.3 (R3.1), RN6.4 (R4.1), RN8.1 (R1.1), RN8.2 (R2.1), RN8.3 (R3.1), RN8.4 (R4.1), RN10.5 (R4.2), RN10.6 (R3.2), RN10.7 (R2.2), RN10.8 (R1.2), RN12.5 (R4.2), RN12.6 (R3.2), RN12.7 (R2.2), RN12.8 (R1.2), U7.3 (GND), U8.6 (GND), U8.18 (GND), U8.28 (GND), U8.39 (GND); also elsewhere on the board
unnamed: J5.1, RN7.7 (R2.2), U8.1 (PB5)
unnamed: J5.5, R25.2, U7.2, U8.4 (~RESET)
unnamed: J5.7, RN7.5 (R4.2), U8.3 (PB7)
unnamed: J5.9, RN7.6 (R3.2), U8.2 (PB6)
unnamed: LED1.2 (DIN), U8.11 (PD2)
unnamed: RN1.8 (R1.2), U8.34 (PA3)
unnamed: RN1.7 (R2.2), U8.35 (PA2)
unnamed: RN1.6 (R3.2), U8.36 (PA1)
unnamed: RN1.5 (R4.2), U8.37 (PA0)
unnamed: RN3.8 (R1.2), U8.30 (PA7)
unnamed: RN3.7 (R2.2), U8.31 (PA6)
unnamed: RN3.6 (R3.2), U8.32 (PA5)
unnamed: RN3.5 (R4.2), U8.33 (PA4)
unnamed: RN5.8 (R1.2), U8.40 (PB0)
unnamed: RN5.7 (R2.2), U8.41 (PB1)
unnamed: RN5.6 (R3.2), U8.42 (PB2)
unnamed: RN5.5 (R4.2), U8.43 (PB3)
unnamed: RN7.8 (R1.2), U8.44 (PB4)
unnamed: RN9.8 (R1.2), U8.19 (PC0)
unnamed: RN9.7 (R2.2), U8.20 (PC1)
unnamed: RN9.6 (R3.2), U8.21 (PC2)
unnamed: RN9.5 (R4.2), U8.22 (PC3)
unnamed: RN11.8 (R1.2), U8.23 (PC4)
unnamed: RN11.7 (R2.2), U8.24 (PC5)
unnamed: RN11.6 (R3.2), U8.25 (PC6)
unnamed: RN11.5 (R4.2), U8.26 (PC7)
unnamed: C10.1, U8.8 (XTAL1), Y1.3
unnamed: C11.2, U8.7 (XTAL2), Y1.1
SCL1: R27.2, U8.13 (PD4); also elsewhere on the board
SCL2: R29.2, U8.15 (PD6); also elsewhere on the board
SDA1: R26.2, U8.12 (PD3); also elsewhere on the board
SDA2: R28.2, U8.14 (PD5); also elsewhere on the board
USB_RXD: U8.10 (PD1); also elsewhere on the board
USB_TXD: U8.9 (PD0); also elsewhere on the board
VDUT_EN: U8.16 (PD7); also elsewhere on the board
ZIF1: RN11.4 (R4.1), RN12.1 (R1.1); also elsewhere on the board
ZIF2: RN11.3 (R3.1), RN12.2 (R2.1); also elsewhere on the board
ZIF3: RN11.2 (R2.1), RN12.3 (R3.1); also elsewhere on the board
ZIF4: RN11.1 (R1.1), RN12.4 (R4.1); also elsewhere on the board
ZIF5: RN9.4 (R4.1), RN10.1 (R1.1); also elsewhere on the board
ZIF6: RN9.3 (R3.1), RN10.2 (R2.1); also elsewhere on the board
ZIF7: RN9.2 (R2.1), RN10.3 (R3.1); also elsewhere on the board
ZIF8: RN9.1 (R1.1), RN10.4 (R4.1); also elsewhere on the board
ZIF9: RN3.1 (R1.1), RN4.8 (R1.2); also elsewhere on the board
ZIF10: RN3.2 (R2.1), RN4.7 (R2.2); also elsewhere on the board
ZIF11: RN3.3 (R3.1), RN4.6 (R3.2); also elsewhere on the board
ZIF12: RN3.4 (R4.1), RN4.5 (R4.2); also elsewhere on the board
ZIF13: RN1.1 (R1.1), RN2.8 (R1.2); also elsewhere on the board
ZIF14: RN1.2 (R2.1), RN2.7 (R2.2); also elsewhere on the board
ZIF15: RN1.3 (R3.1), RN2.6 (R3.2); also elsewhere on the board
ZIF16: RN1.4 (R4.1), RN2.5 (R4.2); also elsewhere on the board
ZIF17: RN7.4 (R4.1), RN8.5 (R4.2); also elsewhere on the board
ZIF18: RN7.3 (R3.1), RN8.6 (R3.2); also elsewhere on the board
ZIF19: RN7.2 (R2.1), RN8.7 (R2.2); also elsewhere on the board
ZIF20: RN7.1 (R1.1), RN8.8 (R1.2); also elsewhere on the board
ZIF21: RN5.4 (R4.1), RN6.5 (R4.2); also elsewhere on the board
ZIF22: RN5.3 (R3.1), RN6.6 (R3.2); also elsewhere on the board
ZIF23: RN5.2 (R2.1), RN6.7 (R2.2); also elsewhere on the board
ZIF24: RN5.1 (R1.1), RN6.8 (R1.2); also elsewhere on the board
~SD: U7.4; also elsewhere on the board

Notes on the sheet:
STATUS LED
PROGRAMMER
4k7

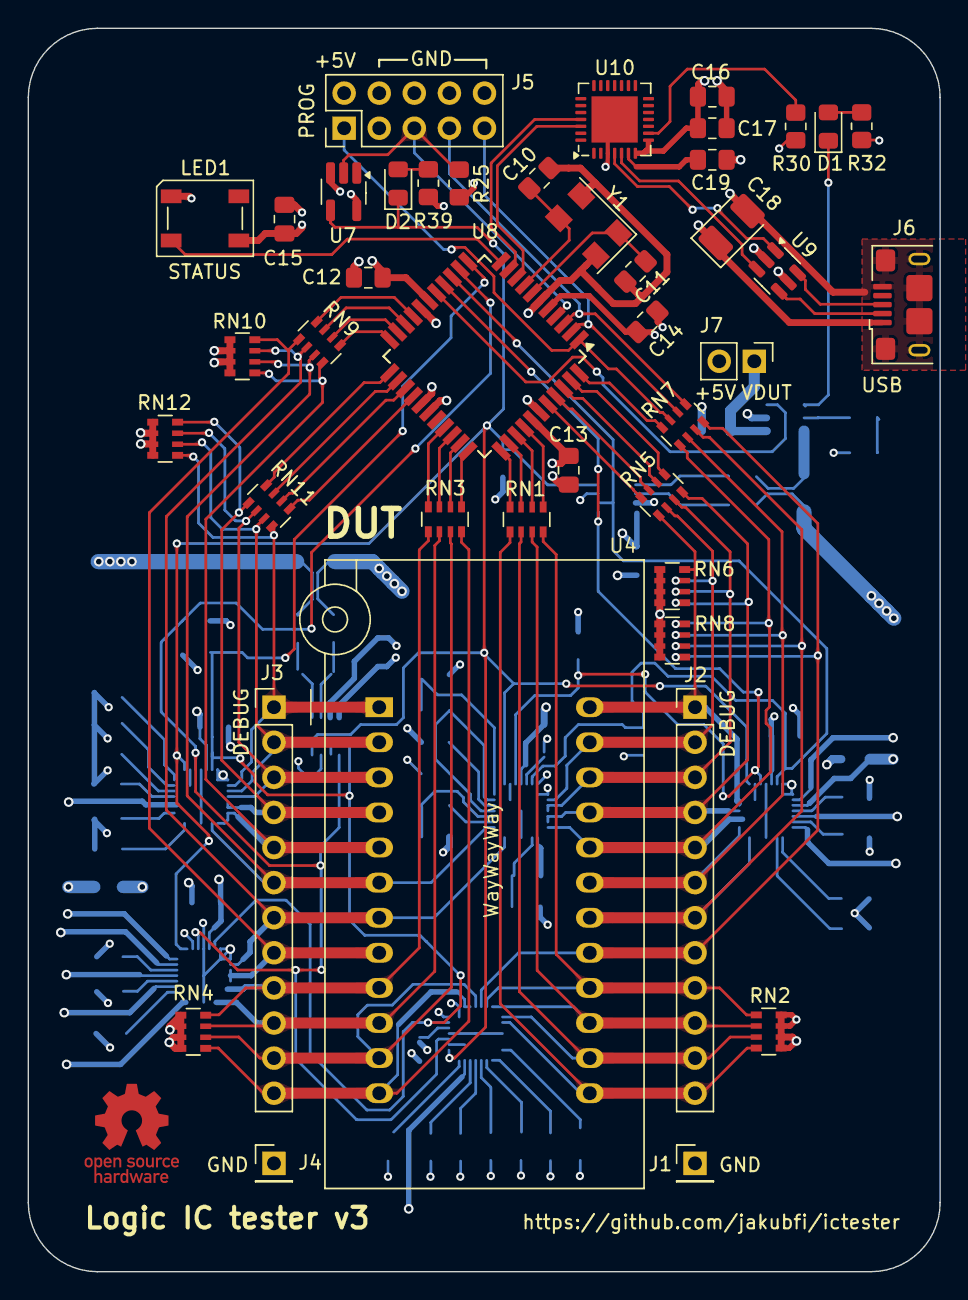
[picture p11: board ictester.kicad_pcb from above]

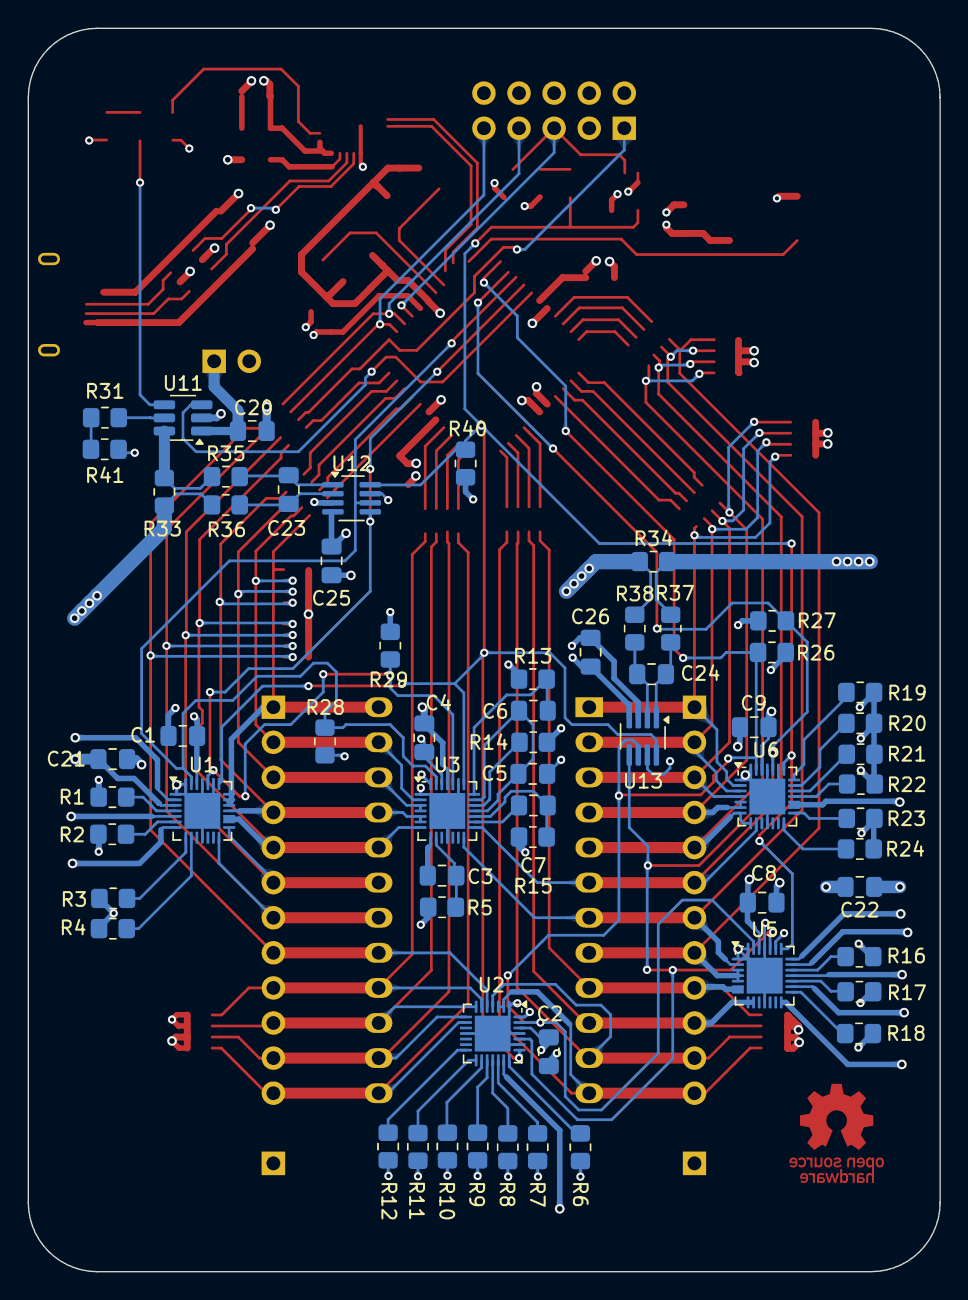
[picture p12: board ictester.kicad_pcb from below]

Board: 4 copper layers, 66.0 x 90.0 mm, 104 parts (61 on the bottom side), 109 nets.

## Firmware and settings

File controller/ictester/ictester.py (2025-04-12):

#!/usr/bin/env python3

import sys
import argparse
import math
import re
import difflib
import logging
import serial.tools.list_ports as listports
from serial.serialutil import SerialException
from colorama import just_fix_windows_console
from colorama import Fore, Back, Style
from struct import unpack

from ictester.test import TestType
from ictester.transport import Transport
from ictester.response import RespType
from ictester.parts import catalog

just_fix_windows_console()

FAIL = Fore.RED + Style.BRIGHT
OK = Fore.GREEN + Style.BRIGHT
WARN = Fore.MAGENTA + Style.BRIGHT
SKIP = Fore.YELLOW + Style.BRIGHT
HI = Fore.WHITE + Style.BRIGHT
LO = Fore.WHITE + Style.DIM
LAB = Fore.BLUE + Style.BRIGHT
ENDC = Style.RESET_ALL

result_color = {
    RespType.HELLO: OK,
    RespType.OK: OK,
    RespType.PASS: OK,
    RespType.FAIL: FAIL,
    RespType.ERR: FAIL,
    RespType.TIMING_ERROR: WARN,
}

logging.basicConfig(format='%(message)s', level=logging.CRITICAL)
logger = logging.getLogger('ictester')

'''
Log levels:
    20 - regular debug
    19 - vector dump
    18 - protocol data
'''

# ------------------------------------------------------------------------
def print_parts(list_tests=False):
    families = {}
    for i in catalog.items():
        family = i[0][0:2]
        if family not in families:
            families[family] = []
        families[family].append(i)

    for family, parts in sorted(families.items()):
        for name, part in sorted(parts, key=lambda x: int(re.sub("74[HSL]+", "74", x[0]))):
            print(f"{name:7s} {part.package_name:6s} {part.desc}")
            if (list_tests):
                for t in part.tests:
                    print(f"  * {t.name} ({len(t.vectors)} vectors)")

# ------------------------------------------------------------------------
def print_part_info(part):
    print(f"Part: {HI}{part.name} ({part.package_name}) - {part.desc}{ENDC}")
    if part.missing_tests:
        print(f"{WARN}WARNING:{ENDC} missing tests: {part.missing_tests}")

# ------------------------------------------------------------------------
def print_vector_chunk(prefix, vector, widths, vector_other=None, color=""):
    print(prefix, end="")
    for n, i in enumerate(vector):
        bitcolor = FAIL if vector_other and i != vector_other[n] else color
        print(f"{bitcolor}{str(i):>{widths[n]+1}}{ENDC}", end="")

# ------------------------------------------------------------------------
def print_vector(label, inputs, outputs, i_width, o_width, i_other=None, o_other=None, color="", separator=""):
    print_vector_chunk(f" {label:<5}", inputs, i_width, i_other, color)
    print_vector_chunk(separator.center(5), outputs, o_width, o_other, color)
    print()

# ------------------------------------------------------------------------
def print_failed_vector(part, test, failed_vector_num, failed_pin_vector, context=3):
    i_failed = [int(failed_pin_vector[pin-1]) for pin in test.inputs]
    o_failed = [int(failed_pin_vector[pin-1]) for pin in test.outputs]

    i_names = [part.pins[pin].name for pin in test.inputs]
    o_names = [part.pins[pin].name for pin in test.outputs]

    i_width = [len(x) for x in i_names]
    o_width = [len(x) for x in o_names]

    print()
    start_vec = max(failed_vector_num - context, 0)
    print_vector("", i_names, o_names, i_width, o_width, color="", separator="->")
    for i in range(start_vec, failed_vector_num+1):
        inputs = [int(x) for x in test.vectors[i].input]
        outputs = [int(x) for x in test.vectors[i].output]
        if i != failed_vector_num:
            print_vector(f"{i}:", inputs, outputs, i_width, o_width, color=LO)
        else:
            print_vector(f"{i}:", i_failed, o_failed, i_width, o_width, inputs, outputs, color=HI)
    print()

# ------------------------------------------------------------------------
def parse_cmd():
    parser = argparse.ArgumentParser(description='IC tester controller')
    parser.add_argument('-d', '--device', default=None, help='Serial port where the IC tester is connected')
    parser.add_argument('-l', '--loops', type=int, default=None, help='Loop count (1..65535)')
    parser.add_argument('-t', '--test', type=int, default=None, help='Test number to run')
    parser.add_argument('-D', '--delay', type=float, default=None, help='additional DUT output read delay in μs (for logic tests only, 13107 μs max, rounded to nearest 0.2 μs)')
    parser.add_argument('-L', '--list', action="store_true", help='List all supported parts')
    parser.add_argument('-A', '--list-all', action="store_true", help='List all supported parts and all tests for each part')
    parser.add_argument('--safety-off', action="store_true", help='Disable safety checks')
    parser.add_argument('-v', '--verbose', action="count", default=0, help='Verbose output. Repeat for even more verbosity')
    parser.add_argument('part', help='Part symbol', nargs='?')
    args = parser.parse_args()

    logger.setLevel(21 - args.verbose)

    if args.test is not None and args.test <= 0:
        parser.error("Test numbers start from 1")

    if args.loops is not None and (args.loops <= 0 or args.loops > 65535):
        parser.error("Loops should be between 1 and 65535")

    if args.delay is not None and (args.delay < 0 or args.delay > 13107):
        parser.error("Delay should be between 0 and 13107")

    if not args.list and not args.list_all and args.part is None:
        parser.error("'part' argument is required")

    return args

# ------------------------------------------------------------------------
def get_part(part_name):
    try:
        part = catalog[part_name]
    except KeyError:
        print(f"Part \"{part_name}\" not found. Use --list to list all supported parts.")
        matches = difflib.get_close_matches(part_name, catalog, n=1, cutoff=0.7)
        if matches:
            matches = ', '.join(matches)
            print(f"Supported part with the most similar name is: {HI}{matches}{ENDC}")
        sys.exit(100)
    return part

# ------------------------------------------------------------------------
def get_serial_port(device):
    # Try searching for ictester
    detected_device = None
    for port in listports.comports():
        if port.manufacturer == "mera400.pl" and port.product == "ictester":
            detected_device = port.device

    serial_port = device if device else detected_device

    # Device not found
    if not serial_port:
        print("No ictester found. Please specify device with --device argument.")
        sys.exit(90)

    return serial_port

# ------------------------------------------------------------------------
# --- Main ---------------------------------------------------------------
# ------------------------------------------------------------------------

def main():
    args = parse_cmd()

    if args.list or args.list_all:
        print_parts(list_tests=args.list_all)
        sys.exit(0)

    part = get_part(args.part.upper())
    serial_port = get_serial_port(args.device)

    try:
        transport = Transport(serial_port, 500000)
    except SerialException as e:
        print(f"Could not open connection to the tester: {e}")
        sys.exit(80)

    part.setup(transport)

    if args.test:
        try:
            run_tests = [part.tests[args.test-1]]
        except IndexError:
            print(f"Test number {args.test} is not available for {part.name}")
            sys.exit(70)
    else:
        run_tests = part.tests

    longest_desc = max(len(t.name) for t in run_tests)

    total_time = 0

    print_part_info(part)
    print()

    tests_failed = 0
    tests_warning = 0
    tests_passed = 0

    print("DUT power up: ", end="")
    resp = part.powerup(transport, args.safety_off)
    vbus = unpack("<h", resp.payload)[0] * 1.6 / 1000
    if resp.response == RespType.OK:
        print(f"{OK}OK{ENDC}, ", end="");
    else:
        print(f"{FAIL}Overcurrent{ENDC}, ", end="")
    print(f"Vbus idle = {HI}{vbus:5.3f} V{ENDC}");
    print()
    if resp.response == RespType.ERR and not args.safety_off:
        return 3

    for test in run_tests:
        loops = args.loops if args.loops is not None else test.loops
        plural = "s" if loops != 1 else ""
        stats = f"({len(test.vectors)} vectors, {loops} loop{plural})"
        endc = "\n" if logger.isEnabledFor(20) else ""
        print(f" * Testing: {HI}{test.name:{longest_desc}s}{ENDC}   {stats:25}  ... ", end=endc, flush=True)

        if tests_failed:
            print(f"\b\b\b\b{SKIP}SKIP{ENDC}")
            resp.response = None
            continue

        if args.delay is not None:
            test.set_delay(args.delay)
        test.setup(transport)

        resp = test.run(transport, loops)

        print(f"\b\b\b\b{result_color[resp.response]}{resp.response.name}{ENDC}", end="")
        if resp.response in (RespType.PASS, RespType.FAIL):
            print(f"  ({test.elapsed:.2f} sec.)", end="")
        print()

        if resp.response == RespType.FAIL:
            tests_failed += 1
            if test.type == TestType.LOGIC:
                print()
                print(f"Test failed on loop: {HI}{test.failed_loop}{ENDC}")
                print_failed_vector(part, test, test.failed_vector_num, test.failed_pin_vector)
            if test.type == TestType.DRAM:
                print()
                print(f" Failing address: row {HI}{test.failed_row}{ENDC}, column {HI}{test.failed_column}{ENDC} on MARCH C- step {HI}{test.failed_march_step}{ENDC}")
                print()
        elif resp.response == RespType.PASS:
            tests_passed += 1
        elif resp.response == RespType.TIMING_ERROR:
            tests_warning += 1

    part.disconnect(transport)

    if resp.response != RespType.FAIL:
        print()

    print(f"Lowest measured bus voltage: {HI}{part.vbus:5.3f} V{ENDC}")
    print(f"Current measurements:")
    print()
    print(f"             Ivcc [mA]   Ignd [mA]   𝚫I [mA]")
    measurements = [f"@max Ivcc", f"@max Ignd", f"@min Ivcc", f"@min Ignd"]
    for name, m in zip(measurements, part.imeasurements):
        print(f" {name}:  {HI}{m[0]:6.2f}      {m[1]:6.2f}      {m[2]:6.2f}{ENDC}")
    print()

    logger.log(20, "Bytes sent: %s, received: %s", transport.bytes_sent, transport.bytes_received)

    tests_skipped = len(part.tests) - (tests_failed + tests_warning + tests_passed)

    print(f"Total tests: {HI}{len(run_tests)}{ENDC}", end="")
    if tests_failed:
        print(f", failed: {FAIL}{tests_failed}{ENDC}", end="")
    if tests_warning:
        print(f", warning: {WARN}{tests_warning}{ENDC}", end="")
    if tests_skipped:
        print(f", skipped: {SKIP}{tests_skipped}{ENDC}", end="")
    if tests_passed:
        print(f", passed: {OK}{tests_passed}{ENDC}", end="")
    print()

    if tests_failed:
        result = f"{FAIL}PART DEFECTIVE"
        ret = 1
    elif tests_warning:
        result = f"{WARN}OUTPUT READ TIMING ERROR"
        ret = 2
    else:
        result = f"{OK}PART OK"
        ret = 0

    print(f"{result}{ENDC}")

    return ret

if __name__ == "__main__":
    sys.exit(main())

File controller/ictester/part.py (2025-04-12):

import inspect
import logging
from enum import Enum
from ictester.command import CmdType
from ictester.response import (Response, RespType)
from struct import (iter_unpack, unpack)

logger = logging.getLogger('ictester')


# ------------------------------------------------------------------------
PinType = Enum("PinType", ["IN", "OUT", "BIDI", "OC", "ST3", "OE", "C", "RC", "VCC", "GND", "NC"])
ZIFFunc = Enum("ZIFFunc", names=[
        ("OUT", 1),
        ("IN_HIZ", 2),
        ("IN_PU_STRONG", 3),
        ("IN_PU_WEAK", 4),
        ("OUT_SINK", 5),
        ("C", 6),
        ("OUT_SOURCE", 7),
        ("VCC", 128),
        ("GND", 129),
    ]
)
Package = Enum("Package",
    names=[
        ("DIP", 1),
    ]
)

# ------------------------------------------------------------------------
class Pin:

    _pin_zif_allowed_funcs = {
        PinType.IN: [ZIFFunc.OUT],
        PinType.OUT: [ZIFFunc.IN_PU_WEAK, ZIFFunc.IN_PU_STRONG, ZIFFunc.IN_HIZ],
        PinType.BIDI: [ZIFFunc.OUT, ZIFFunc.IN_PU_WEAK, ZIFFunc.IN_PU_STRONG, ZIFFunc.IN_HIZ],
        PinType.OC: [ZIFFunc.IN_PU_STRONG, ZIFFunc.IN_PU_WEAK, ZIFFunc.IN_HIZ],
        PinType.ST3: [ZIFFunc.IN_PU_WEAK, ZIFFunc.IN_HIZ, ZIFFunc.IN_PU_STRONG],
        PinType.OE: [ZIFFunc.OUT_SINK],
        PinType.C: [ZIFFunc.C],
        PinType.RC: [ZIFFunc.IN_PU_STRONG],
        PinType.VCC: [ZIFFunc.VCC],
        PinType.GND: [ZIFFunc.GND],
        PinType.NC: [ZIFFunc.IN_HIZ],
    }

    _pin_zif_default_funcs = {
        PinType.IN: [ZIFFunc.OUT],
        PinType.OUT: [ZIFFunc.IN_PU_WEAK],
        PinType.BIDI: None,
        PinType.OC: [ZIFFunc.IN_PU_STRONG],
        PinType.ST3: [ZIFFunc.IN_PU_WEAK],
        PinType.OE: [ZIFFunc.OUT_SINK],
        PinType.C: [ZIFFunc.C],
        PinType.RC: [ZIFFunc.IN_PU_STRONG],
        PinType.VCC: [ZIFFunc.VCC],
        PinType.GND: [ZIFFunc.GND],
        PinType.NC: [ZIFFunc.IN_HIZ],
    }

    def __init__(self, name, role, zif_func=None):
        assert role in self._pin_zif_allowed_funcs
        self.name = name
        self.role = role

        if zif_func:
            self.zif_func = zif_func
        else:
            self.zif_func = self._pin_zif_default_funcs[role]

        if not self.zif_func:
                raise ValueError(f"Pin {self.name} which is of type {self.role.name} requires zif_func to be defined")
        else:
            for f in self.zif_func:
                if f not in self._pin_zif_allowed_funcs[role]:
                    raise ValueError(f"ZIF function: {f.name} cannot be assigned to pin type: {self.role.name}")


# ------------------------------------------------------------------------
class Part:
    pincount = 0
    package_type = None
    package_pins = {}
    name = None
    tests = None
    missing_tests = None

    def __init__(self):
        self.imeasurements = []
        self.pins = {}
        self.pins.update(self.package_pins)
        self.pins.update(self.pin_cfg)

        for t in self.tests:
            t.attach_part(self)

    @property
    def package_name(self):
        return f"{self.package_type.name}{self.pincount}"

    @property
    def vcc(self):
        return list(k for k, v in self.pins.items() if v.role == PinType.VCC)

    @property
    def gnd(self):
        return list(k for k, v in self.pins.items() if v.role == PinType.GND)

    def __bytes__(self):
        data = []
        cfg_count = 0
        for pin in self.pins.values():
            if len(pin.zif_func) > cfg_count:
                cfg_count = len(pin.zif_func)
        assert 5 > cfg_count > 0
        data.extend([self.package_type.value, self.pincount, cfg_count])

        logger.log(20, "DUT pin definitions, %s configuration(-s) available:", cfg_count)

        for cfgnum in range(0, cfg_count):
            logger.log(20, "Configuration %s:", cfgnum)
            for num, pin in sorted(self.pins.items()):
                try:
                    pin_func = pin.zif_func[cfgnum]
                except IndexError:
                    pin_func = pin.zif_func[0]
                logger.log(20, '%3s %6s %5s ZIF %s', num, pin.name, pin.role.name, pin_func.name)
                data.append(pin_func.value)

        return bytes(data)

    def setup(self, tr):
        logger.log(20, "---- DUT SETUP ------------------------------------")
        data = bytes([CmdType.DUT_SETUP.value]) + bytes(self)
        tr.send(data)
        resp = Response(tr)

    def powerup(self, tr, safety_off):
        logger.log(20, "---- DUT POWERUP ----------------------------------")
        data = bytes([CmdType.DUT_POWERUP.value, safety_off])
        tr.send(data)
        resp = Response(tr)
        return resp

    def disconnect(self, tr):
        logger.log(20, "---- DUT DISCONNECT -------------------------------")
        data = bytes([CmdType.DUT_DISCONNECT.value])
        tr.send(data)
        resp = Response(tr)
        self.vbus = unpack("<h", resp.payload[0:2])[0] * 1.6 / 1000
        for x in iter_unpack("<hh", resp.payload[2:]):
            shunt_to_ma = 1000 * 0.0000025 / 0.200  # 1000 * 2.5uV / 200mohm
            ivcc = x[0] * shunt_to_ma
            ignd = x[1] * shunt_to_ma
            idelta = abs(ivcc-ignd)
            self.imeasurements.append([ivcc, ignd, idelta])


# ------------------------------------------------------------------------
class PackageDIP14(Part):
    pincount = 14
    package_type = Package.DIP
    package_pins = {
        7: Pin("GND", PinType.GND),
        14: Pin("VCC", PinType.VCC),
    }


# ------------------------------------------------------------------------
class PackageDIP14_vcc5(Part):
    pincount = 14
    package_type = Package.DIP
    package_pins = {
        5: Pin("VCC", PinType.VCC),
        10: Pin("GND", PinType.GND),
    }


# ------------------------------------------------------------------------
class PackageDIP14_vcc4(Part):
    pincount = 14
    package_type = Package.DIP
    package_pins = {
        4: Pin("VCC", PinType.VCC),
        11: Pin("GND", PinType.GND),
    }


# ------------------------------------------------------------------------
class PackageDIP16(Part):
    pincount = 16
    package_type = Package.DIP
    package_pins = {
        8: Pin("GND", PinType.GND),
        16: Pin("VCC", PinType.VCC),
    }


# ------------------------------------------------------------------------
class PackageDIP16_rotated(Part):
    pincount = 16
    package_type = Package.DIP
    package_pins = {
        8: Pin("VCC", PinType.VCC),
        16: Pin("GND", PinType.GND),
    }


# ------------------------------------------------------------------------
class PackageDIP16_vcc5(Part):
    pincount = 16
    package_type = Package.DIP
    package_pins = {
        5: Pin("VCC", PinType.VCC),
        12: Pin("GND", PinType.GND),
    }
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

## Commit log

2020-12-15 add pin maps for DIP16 and DIP24
2020-12-17 bunch of changes
    * add 7430,
    * continue 74181,
    * rename negated pins,
    * Test() class
    * per-test test vectors
    * per-test pin setup
2021-05-18 add DIP16 with alternative power, add 7483
2021-05-22 exit with 1 on error, rework loops, per-test loops
    [ictester.py]
2021-12-01 fix sorting for 74H and 74S
    [ictester.py]
2022-10-28 refactor pins, package variants, add sanity checks, fix 7475
    [ictester.py]
2022-11-04 inform about unusual power pins
2022-12-17 simplify catalog and its printout
2022-12-18 case-insensitive part name matching
2023-06-29 fix listing LS chips
    [ictester.py]
2023-07-01 use lower-case file names
2023-07-03 Make the H/W responsible for pin mapping. Also:
    * --serial_debug is now --debug-serial
    * remove total time measurement (makes no sense)
    * update protocol to be closer to the final one
    * clean up prototypes (properties, package naming, etc.)
2023-07-03 BV byte conversion, Tester.send bytes, debug fixes
    [binvec.py]
2023-07-03 move const structs to flash, cleanup socket guessing
2023-07-04 use loops instead of loops power
2023-07-06 add kicad files
    [ictester.kicad_pcb, ictester.kicad_sch]
2023-07-09 h/w update
    [ictester.kicad_pcb, ictester.kicad_sch]
2023-07-21 hw update
    [ictester.kicad_pcb, ictester.kicad_sch]
2023-08-06 Initial version for the new H/W. Also fix 74H106.
    [ictester.py]
2023-08-25 fix LED status, more sane result handling
2023-09-02 late connect, early disconnect, skip after fail
    [ictester.py]
2023-09-03 SEQ and COMB are now LOGIC
    * make SEQ and COMB tests into LOGIC tests
    * allow None as output in vector definition (i.e. vector not checked)
    * vectors with '+' or '-' bit values are expanded to 2-vectors
    * send "skip vector check" flag as VCC bit in the vector
    * simplify Test.body/Test.vectors situation
    * fw: store "skip check" separately for each vector and use it to make
    the check decision
    * few other minor fixes
    [ictester.py]
2023-09-04 sequential circuits testing changes
    * change old meaning, introduce new sequential 'bits':
    '/' - rising edge, '\\' - falling edge,
    '+' - positive impulse, '-' - negative impulse
    * update existing sequential ICs
    * fix 74198
    * update qc
2023-09-05 74123 rework
    * drop .trig_loops, use constant RETRIG_LOOPS
    * add .val_clear_trig, add test for triggering with rising CLR
    * fix issue witn 74hct123 sensitive to non-trigger changes (unwanted CLR trigger case)
    * cleanup trigger and output check functions
    * fix output checking
    * add comments
2023-09-09 no strict prototypes, janitorial
2023-09-10 pin masking - naming changes
2023-09-10 Device autodetection
2023-09-13 Check for test timing errors
    [ictester.py]
2023-09-14 report the failed vector
    [ictester.py, transport.py]
2023-09-15 name matching + main() janitorial
    * IC with a similar name is suggested when no exact match found
    * separate some main() functions
    * open serial port late
    * handle serial port open errors
    * cleanups, renames
    [ictester.py, transport.py]
2023-09-15 make led.c more sane
2023-09-17 Towards The Protocol part III
    * pin usage data required for LOGIC tests only
    * inputs/outputs are not required for dram and univibs anymore
    * MAX_PARAMS is now 2
    * more Enums (dram and univib)
    * dram test constructor args order fix
    * protocol doc update
2023-09-17 janitorial, small fixes, enum for Package
    [ictester.py, transport.py]
2023-09-18 logging
    * use logging instead of hand-crafted debug
    * --verbose instead of --debug*
    * add short versions of cmdline options
    * simplify transport verbose output
    [ictester.py, transport.py]
2023-09-18 rework main loop a bit
    [ictester.py]
2023-09-21 The Protocol part I
    * framing for command side of the protocol, protocol structs
    * *_test_setup() - test specific setups
    * test parameters are now test-specific
    * pin masking is now specific to LOGIC tests
    * cfgnum handled with a pointer to config internally + zif_config_select()
    * vectors can be loaded by chunks
    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
2023-09-24 The Protocol part II
    * framing for the response side of the protocol; structs
    * minimal handling of framed responses on SW side, needs more work
    * *_store_result() on test side of processing
    * handling failure details for mem test
    [ictester.py, transport.py]
2023-09-24 The Protocol part III
    * DUT and Test related commands moved to Part and Test
    * move test result decoding to Test
    * drop Tester class alltogether
    * read delay available for all tests (but test may ignore it)
    * elapsed time measured by the test, test result stats done in
    ictester.py
    * fix stats in transport
    [ictester.py, response.py, transport.py]
2023-09-24 split prototypes.py
2023-09-24 The Protocol part IV - error handling
    [part.py, response.py]
2024-06-22 report failing loop number
    [ictester.py]
2024-11-30 fix parts listing with short switches
    [ictester.py]
2025-04-16 H/W v3
    [ictester.kicad_pcb, ictester.kicad_sch, isense.kicad_sch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]
2025-04-16 update schematic
    [ictester.kicad_sch, isense.kicad_sch, mcu.kicad_sch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]
2025-04-22 improve oscillator grounding
    [ictester.kicad_pcb, mcu.kicad_sch]
2025-04-26 generalize current statistics
2025-04-26 minimal current measurement for univibs
2025-04-30 Specify INA236A, add note about INA236A/B variants
    [isense.kicad_sch]
